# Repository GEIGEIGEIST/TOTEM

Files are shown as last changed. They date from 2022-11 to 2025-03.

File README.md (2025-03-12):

<picture align="center">
  <source media="(prefers-color-scheme: dark)" srcset="/docs/images/TOTEM_logo_dark.svg">
  <source media="(prefers-color-scheme: light)" srcset="/docs/images/TOTEM_logo_bright.svg">
  TOTEM logo
</picture>

<h1 align="center">T O T E M</h1>

TOTEM is a 38 key column-staggered choc split keyboard. It is meant to be used with a [Seeed Studio XIAO nRF52840 BLE](https://www.seeedstudio.com/Seeed-XIAO-BLE-nRF52840-p-5201.html) or [XIAO RP2040](https://www.seeedstudio.com/XIAO-RP2040-v1-0-p-5026.html).
It was created for the SEEED XIAO keyboard contest.\
[Here](https://www.hackster.io/geist/totem-a-tiny-splitkeyboard-with-splay-cb2e43) you can read about the process of making it.

***

## LAYOUT

TOTEM layout

***

## PCB

[Here](/PCB/) you can find the KiCad files and Gerbers for the TOTEM.

***

## CASE

You can use the TOTEM without a case, but [here](/case/) you can find one I made for it.

***

## BUILD GUIDE

The build guide for the TOTEM can be found [here](/docs/buildguide.md).

***

## FIRMWARE

[QMK (VIAL) precompiled](/firmware/QMK/) or [QMK (VIAL) source](/firmware/QMK/VIAL_source/) for the TOTEM (wired using the XIAO RP2040)\
[ZMK precompiled](/firmware/ZMK/) or [ZMK source (outdated)](https://github.com/GEIGEIGEIST/zmk-config-totem) for the TOTEM (wireless using the XIAO BLE)

***

## BUY

You can buy TOTEM kits and finished builds on [keeb.supply](https://keeb.supply/products/geist-totem) (based in Germany)

***

## PHOTOS

This is the TOTEM in a black resin case

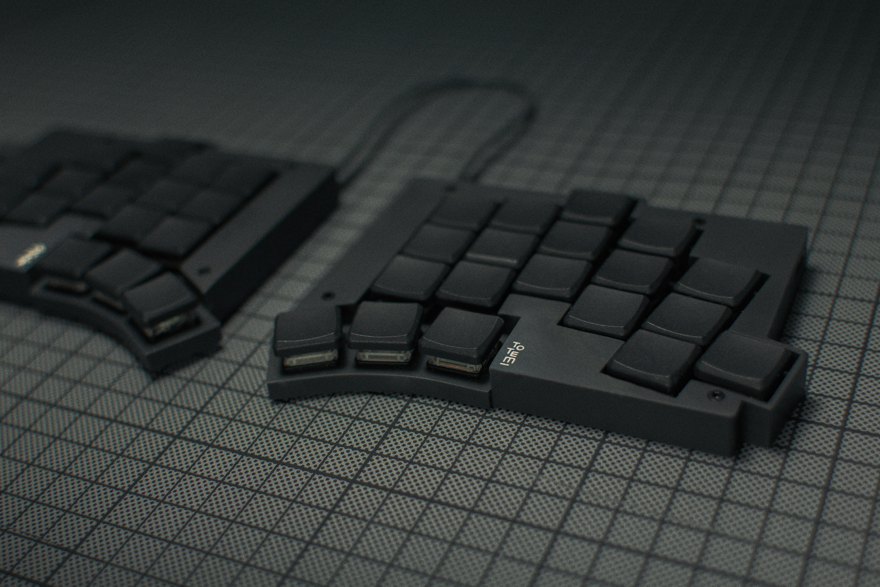
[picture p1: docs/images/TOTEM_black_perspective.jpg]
TOTEM black resin
\
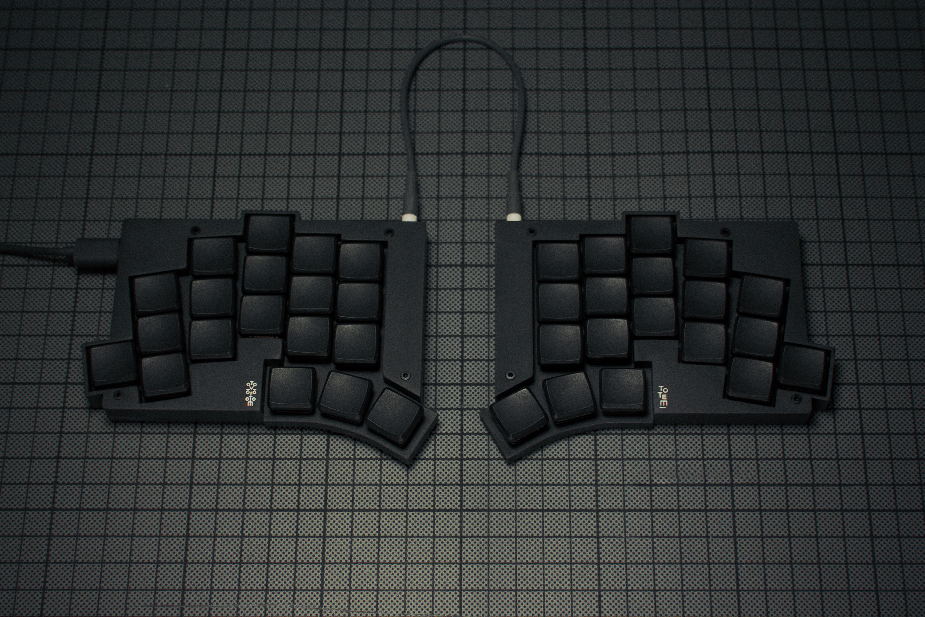
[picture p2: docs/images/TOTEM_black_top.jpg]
TOTEM black resin
\
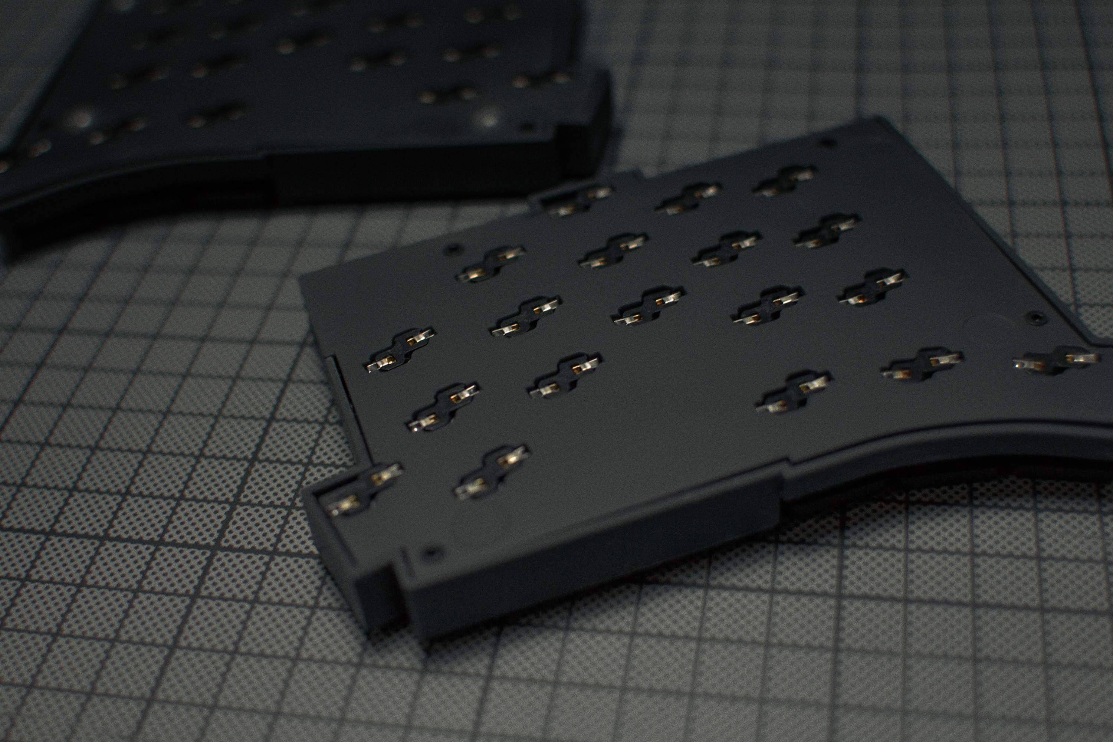
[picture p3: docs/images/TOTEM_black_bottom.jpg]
TOTEM black resin


This is the TOTEM with a black resin tenting bottom plate

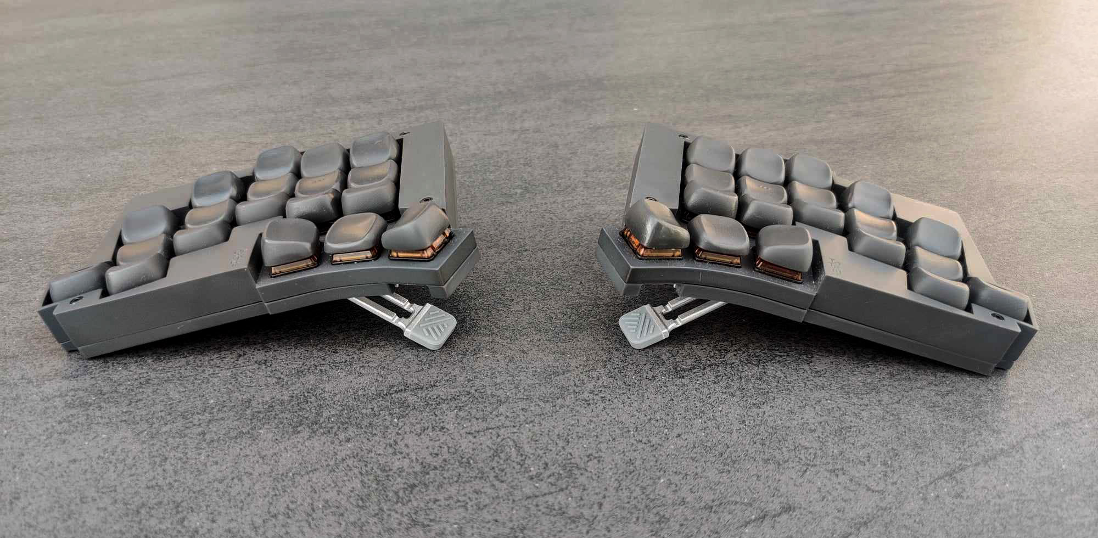
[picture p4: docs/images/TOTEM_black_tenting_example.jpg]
TOTEM black resin tenting
\
[Video by *Wolfgang's Channel* showing the tenting system in action](https://youtu.be/rvM2BthjEI4?si=mTJVdPeZstshnDyo)

***

## CREDITS

### INSPIRATION

I've added the additional pinky key to make the TOTEM compatible with the layout boards like the [Balbuzard](https://github.com/brow/balbuzard) by [Tom Brow](https://github.com/brow) and the [Osprette](https://github.com/smores56/osprette) by [Sam Mohr](https://github.com/smores56) use, where you put the keybinding of the top left and right keys on an outer pinky key.

### HELP FIXING THINGS

People who helped me create this board and fix stuff

#### PCB
- [Marco "Bob"](https://github.com/GroooveBob)

#### CASE
- [Freya](https://github.com/freya-irl)
- [Bubbleology](https://github.com/bubbleology)

#### FIRMWARE
- [Cem Aksoylar](https://github.com/caksoylar)
- [Grinnie](https://github.com/regicidalplutophage)
- [Alaa Saad Mansour](https://github.com/AlaaSaadAbdo)
- [pekudzu](https://github.com/pekudzu)

If you build a TOTEM I would be pretty happy to see some pictures. And if you want to leave me a tip you can do this [here](https://ko-fi.com/geigeigeist) (but please don't feel pressured)

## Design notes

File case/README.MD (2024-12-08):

# TOTEM CASE

Each half consists of a bottom and a top part (with an integrated switchplate) and is meant to be 3D printed in resin. 

I got good results from [JLCPCB](https://cart.jlcpcb.com/quote) (15€ + tax and shipping for a black or white version) and [PCBway](https://www.pcbway.com/rapid-prototyping/manufacture/?type=2&reffercode=TOP) (50€ + tax and shipping for a clear case).

Where possible use the STEP files, but the STL files should be fine too.

If you're sure you only will use the wired version you can also use the case without a power switch (USB) or use the case without a TRRS cutout if you plan on using the wireless version (BLE).

> **Note**
> The manufacturer will probably warn you about too thin sections, but it worked fine for me since these sections are pretty small.

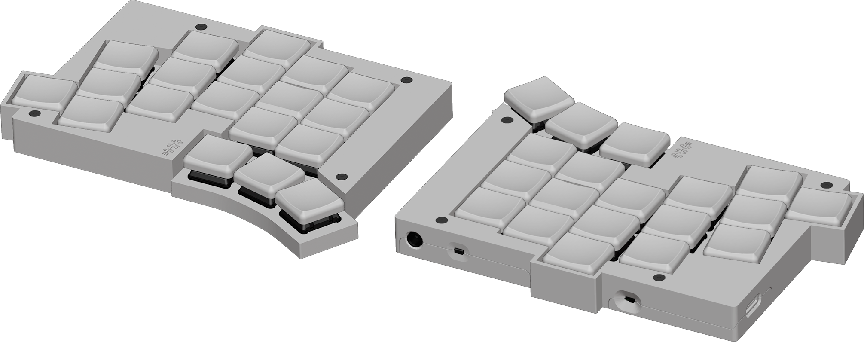
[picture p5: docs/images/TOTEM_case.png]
TOTEM case


## Tenting

Tenting is possible using the provided bottom plates found in the tenting folder. These bottom plates are compatible with their corresponding non-tenting top part. The tenting bottom plates are compatible with the same screws as the non-tenting bottom plates.

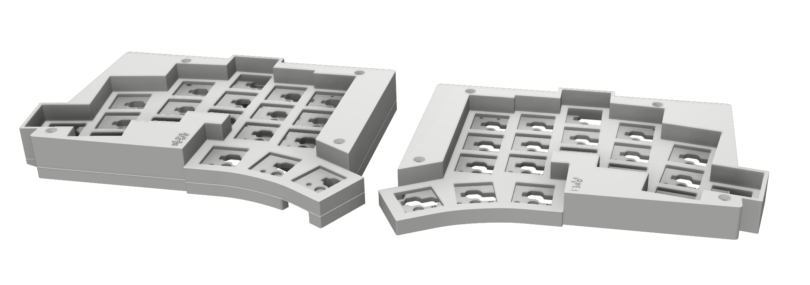
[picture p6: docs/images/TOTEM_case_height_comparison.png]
TOTEM tenting height comparison

> **Note**
>Using these tenting bottom plates (left) the keyboard height will be increased by the thickness of the tenting feet (around 4mm). Compared to the default bottom plate (right).

The tenting bottom plates are designed for [these laptop risers](https://aliexpress.com/item/1005005605228469.html).
These are attached using the provided adhesive and sit flush with the bottom of the plate.

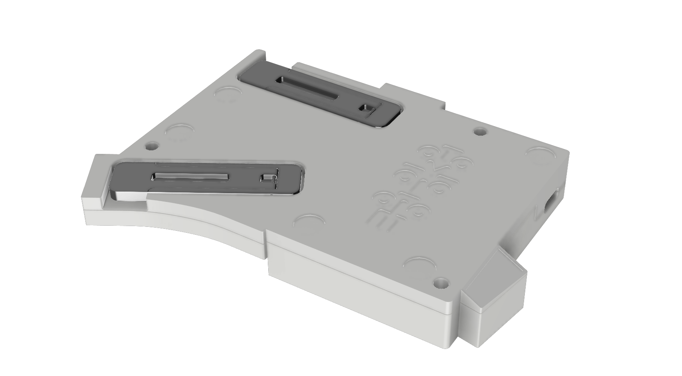
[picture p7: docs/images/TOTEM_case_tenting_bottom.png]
TOTEM tenting bottom


This system enables two tenting options: 13 and 20 degrees.
The feet allow for an even higher tenting option but this is not officially supported due to design constrains for top piece compatibility.

For optional extra grip whilst tenting there is a recess made at the pinky key designed for anti-slip adhesive pads, such as [this one](https://aliexpress.com/item/1005005377684110.html)

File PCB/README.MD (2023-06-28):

# TOTEM PCB FILES

## MANUFACTURING
If you want to get the PCB made you need to download the [ZIP](/PCB/totem_0-3/totem_0-3_gerbers.zip/) and upload it to the website of the manufacture 
I can recommend [JLCPCB](https://jlcpcb.com/), [Seeed Fusion](https://www.seeedstudio.com/fusion_pcb.html) or [PCBway](https://www.pcbway.com/).
If you want the silkscreen in yellow [AllPCB](https://www.allpcb.com/online_pcb_quote_new.html) is a pretty affordable choice.

- download [the ZIP file](/PCB/totem_0-3/totem_0-3_gerbers.zip/)
- upload the ZIP file to the website of the manufacturer.
- sometimes the Gerber preview from JLCPCB can't display the PCB, even when the files are fine. In this case use these dimensions: 258.7mm * 94.35mm
- PCB Thickness 1.6mm
- 2 layers
- PCB Qty as much as you like. One PCB is a full keyboard.
- PCB Color Black (or any other color you like)
- No impedance control
- Surface Finish HASL(with lead) if you want the easiest soldering experience or LeadFree HASL.
- Remove Order Number Yes

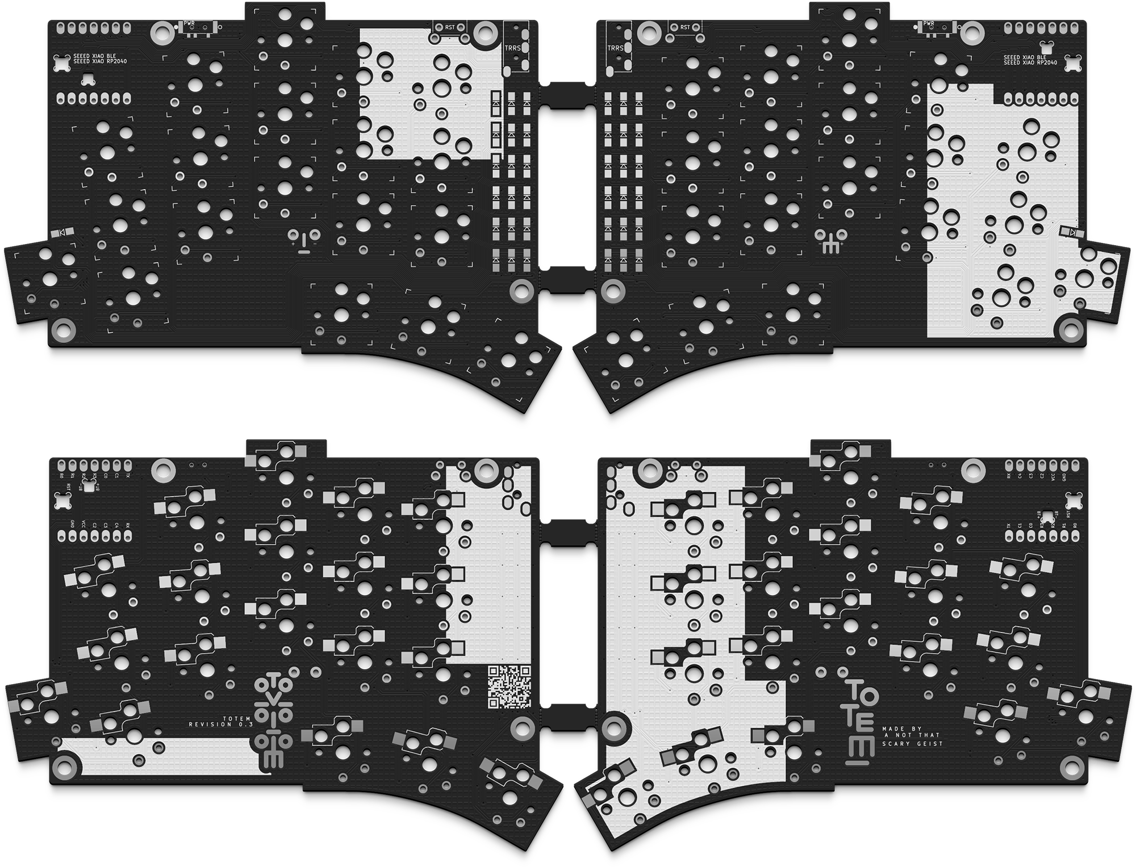
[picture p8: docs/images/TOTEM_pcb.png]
TOTEM PCB


***

## CHECK PINOUT OR TRACES

If you only want to check the traces or see what is connected to which pin you can take a look at these graphics.
You can also take a look at the [schematics](TOTEM_0-3_schematics.pdf) and the [PCB](TOTEM_0-3_PCB.pdf) as PDF.

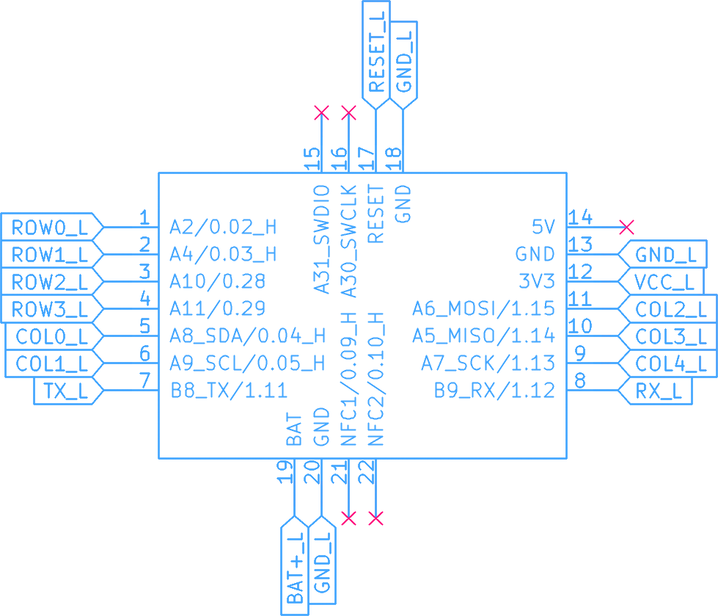
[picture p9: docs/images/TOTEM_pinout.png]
TOTEM pinout


***

TOTEM traces

***

## TAKE A DEEPER LOOK OR MODIFY 

You can download the project if you need to take a deeper look or modify something. You need the Open Source software [KiCad](https://www.kicad.org/) to open it.

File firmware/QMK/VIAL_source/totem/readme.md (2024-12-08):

```
                                                       ▀▀▀▀▀     ▀▀▀▀▀          ▀▀█▀▀
                                                       ▄▀▀▀▄  ▄  ▄▀▀▀▄  ▄  ▄▀▀▀▄  █  ▄▀▀▀▄
                                                       █   █  █  █   █  █  █   █  █  █   █
                                                        ▀▀▀   █   ▀▀▀   █   ▀▀▀   ▀   ▀▀▀
                                                              █      ▄▄▄█▄▄▄    █   █  
                                                              ▀      █  █  █     █▄█
                                                            ▀▀▀▀▀    █  █  █      ▀
                                                                     ▀  ▀  ▀
▄▄▄▄▄▄▄▄▄▄▄▄▄▄▄▄▄▄▄▄▄▄▄▄▄▄▄▄▄▄▄▄▄▄▄▄▄▄▄▄▄▄▄▄▄▄▄▄▄▄▄▄▄▄▄▄▄▄▄▄▄▄▄▄▄▄▄▄▄▄▄▄▄▄▄▄▄▄▄▄▄▄▄▄▄▄▄▄▄▄▄▄▄▄▄▄▄▄▄▄▄▄▄▄▄▄▄▄▄▄▄▄▄▄▄▄▄▄▄▄▄▄▄▄▄▄▄▄▄▄▄▄▄▄▄▄▄▄▄▄▄▄▄▄▄▄▄▄▄
       
```
# TOTEM split keyboard

TOTEM is 34 keys column-staggered split keyboard made by @geigeigeist. It uses the Seeed XIAO RP2040.

You can use this command to compile the firmware
`qmk compile -kb totem -km default`

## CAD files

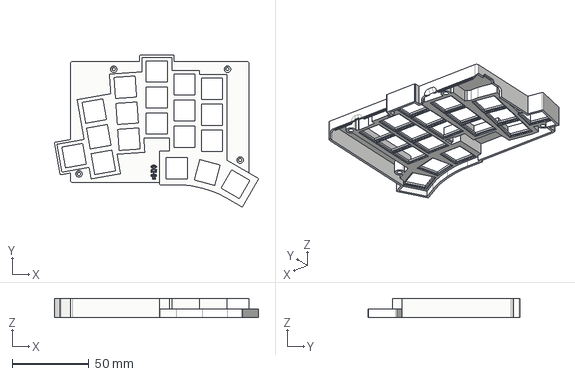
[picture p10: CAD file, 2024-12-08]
case/BLE/STEP/TOTEM_case_ble_top_L_V.08.step
133.1 x 99.0 x 12.5 mm

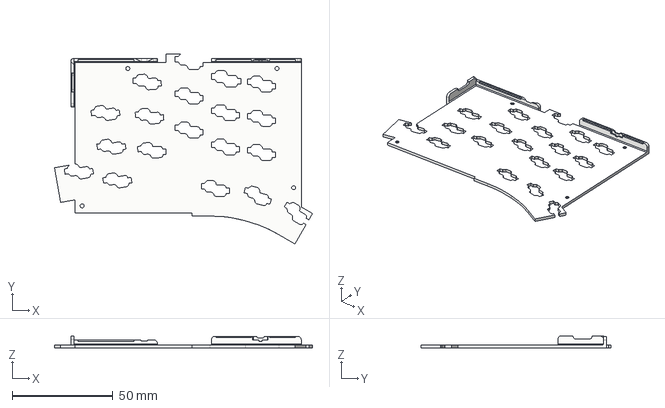
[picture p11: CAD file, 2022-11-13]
case/NoTRRS/STEP/TOTEM case_v06_noTRRS_bottomLeft.step
128.3 x 94.5 x 6.20 mm

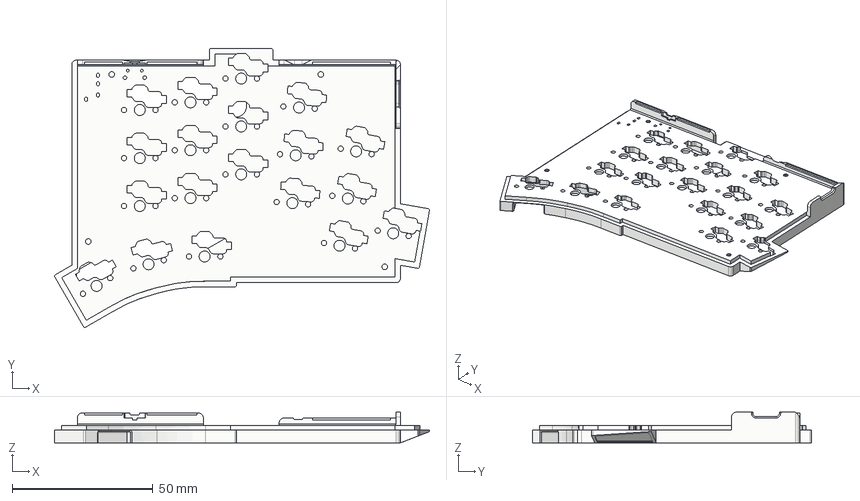
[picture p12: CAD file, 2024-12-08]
case/tenting/BLE/step/TOTEMcase_v08_6mm_BLE_Tenting_Bottom_R.step
133.1 x 99.0 x 10.9 mm

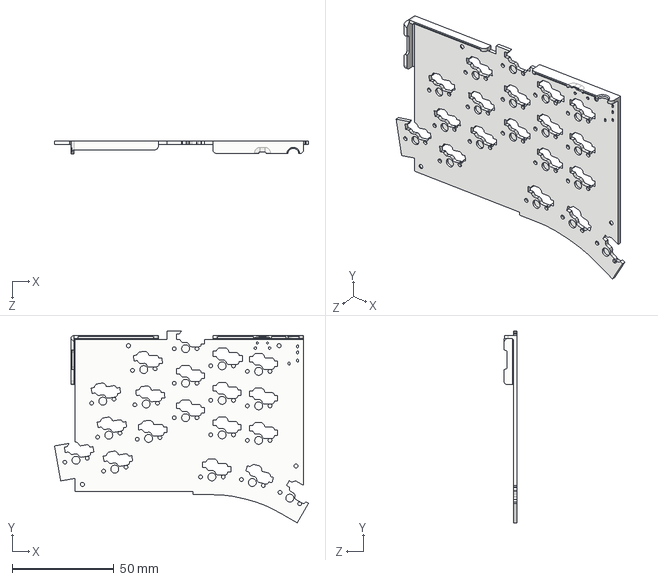
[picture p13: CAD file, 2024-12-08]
case/USB/STEP/TOTEM_case_usb_bottom_L_V.08.step
125.1 x 94.5 x 6.40 mm

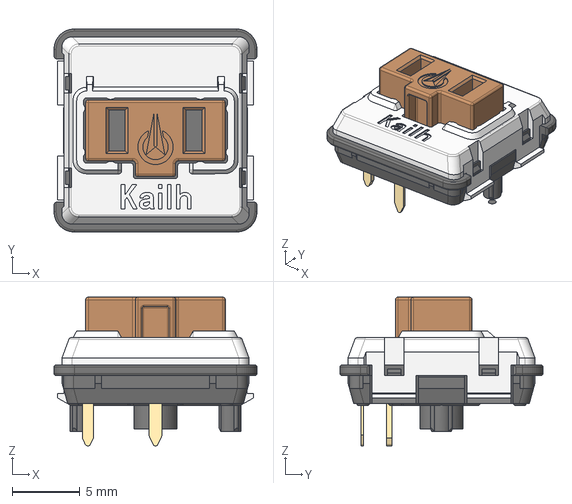
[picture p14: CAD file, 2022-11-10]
PCB/totem_0-3/TOTEM3D/Kailh_switch_PG1350_optional.step
15.0 x 15.0 x 11.0 mm

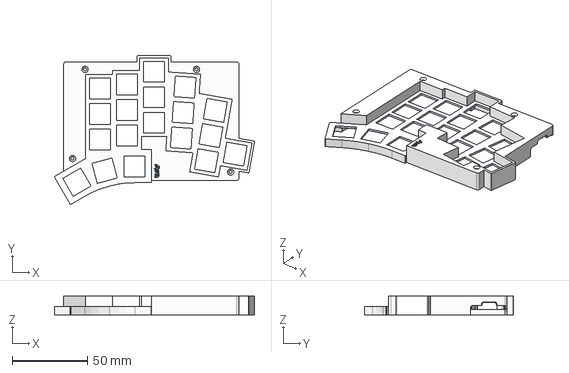
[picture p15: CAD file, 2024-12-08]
case/USB/STEP/TOTEM_case_usb_top_R_V.08.step
133.1 x 99.0 x 12.5 mm

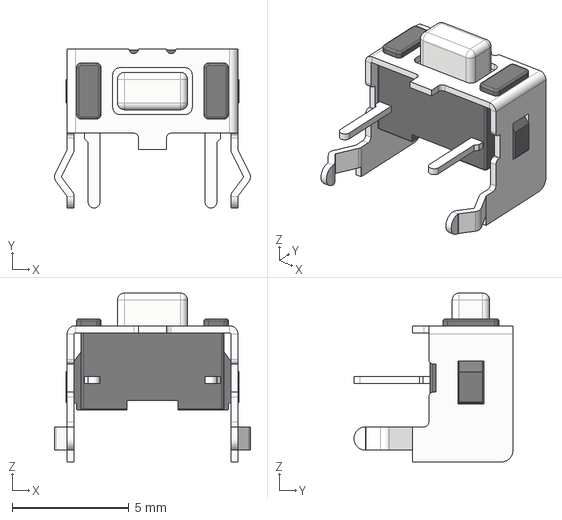
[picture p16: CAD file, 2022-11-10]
PCB/totem_0-3/TOTEM3D/SW_SKHLLC.step
8.38 x 6.80 x 7.22 mm

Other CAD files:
case/STEP/TOTEM_case_v06_Rbottom.step
case/tenting/TRX/STEP/TOTEMcase_v08_6mm_TRX_Tenting_Bottom_R.step
case/tenting/USB/STEP/TOTEMcase_v08_6mm_USB_Tenting_Bottom_L.step
case/BLE/STEP/TOTEM_case_ble_bottom_R_V.08.step
case/NoTRRS/STEP/TOTEM case_v06_noTRRS_bottomRight.step
case/STEP/TOTEM_case_v06_Lbottom.step
case/tenting/BLE/step/TOTEMcase_v08_6mm_BLE_Tenting_Bottom_L.step
case/tenting/TRX/STEP/TOTEMcase_v08_6mm_TRX_Tenting_Bottom_L.step
case/tenting/USB/STEP/TOTEMcase_v08_6mm_USB_Tenting_Bottom_R.step
case/BLE/STEP/TOTEM_case_ble_bottom_L_V.08.step
case/USB/STEP/TOTEM_case_usb_top_L_V.08.step
PCB/totem_0-3/TOTEM3D/D_SOD-123.step
PCB/totem_0-3/TOTEM3D/Kailh_socket_PG1350_optional.STEP
PCB/totem_0-3/TOTEM3D/MSK12C02.STEP
PCB/totem_0-3/TOTEM3D/PJ320A.STEP
PCB/totem_0-3/TOTEM3D/xiao-ble-tht.step
case/BLE/STEP/TOTEM_case_ble_top_R_V.08.step
case/BLE/STL/TOTEM_case_ble_bottom_L_V.08.STL
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

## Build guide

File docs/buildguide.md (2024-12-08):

# TOTEM BUILD GUIDE

## PART LIST

### REQUIRED PARTS

| Part name | Count | Remarks | 
| :---  | :---: | :--- |
| TOTEM PCB | 01 | You can find the files for it [here](/PCB/) |
| Seeed Studio XIAO| 02 | You can choose between the [nRF52840 BLE version (wireless)](https://www.seeedstudio.com/Seeed-XIAO-BLE-nRF52840-p-5201.html) or the [RP2040 version (wired)](https://www.seeedstudio.com/XIAO-RP2040-v1-0-p-5026.html) |
| Choc key switch  | 38 | Kailh Choc low profile key switches |
| diodes 1N4148W | 38 | These are surface mount diodes in SOD123 package |
| 1u Choc keycaps  | 38 | You can use the black or white keycaps from Kailh, but I recommend MBK, LDSA or CFX keycaps |
| reset button | 02 | Alps SKHLLCA010 |
| USB-C cable | 01 | For connecting the keyboard to your PC |
| power switch | 02 | MSK12C02 (only required for the Bluetooth build) |
| Lipo battery | 02 | There is space for a 15 x 22 x 7.5 mm battery (only required for the Bluetooth build) |
| TRRS jack | 02 | MJ-4PP-9 or PJ320A (only required for the wired build)|
| TRRS cable | 01 | Alternatively, you can use a TRS cable for [half-duplex](https://github.com/qmk/qmk_firmware/blob/master/docs/serial_driver.md#usart-half-duplex) (only required for the wired build)|

### OPTIONAL PARTS

| Part name | Count | Remarks | 
| :--- | :---: | :--- |
| switch socket | 38 | Switch sockets for Kailh choc switches |

### 3DP CASE PARTS

| Part name | Count | Remarks | 
| :--- | :---: | :--- |
| 3D printed case | 02 | Find the case files [here](/case) |
| 6mm M2 standoffs | 08 | 6mm round standoffs for screwing the top and bottom of the case together |
| 6mm M2 countersunk screws | 16 ||
| 8.5mm rubber feet | 8 | they can also be smaller |

### TENTING CASE PARTS
| Part name | Count | Remarks | 
| :--- | :---: | :--- |
| Additional 8.5mm rubber feet | 2 | Optional, they can also be smaller |
| Tenting feet | 4 | Example source [here](https://aliexpress.com/item/1005005605228469.html) |
| Anti-Slip adhesive sheet | 1 | Optional, example source [here](https://aliexpress.com/item/1005005377684110.html) |

## INTRODUCTION

Here is an overview of where and on which side each component needs to be soldered (click on the image to see a larger version).

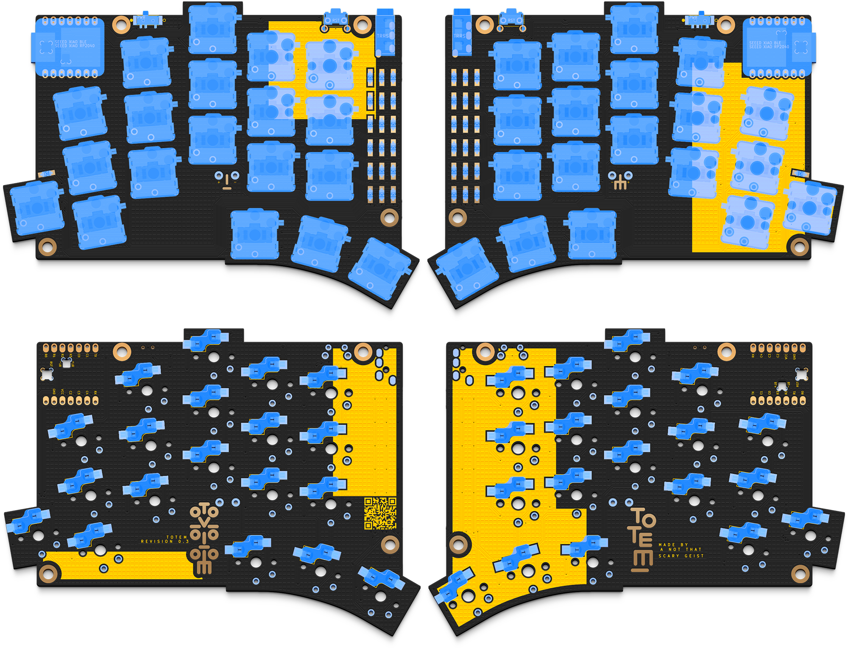
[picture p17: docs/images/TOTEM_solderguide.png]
TOTEM solder guide


***

## BREAK OFF HALVES

The PCB comes in one piece. You need to break it into two halves.

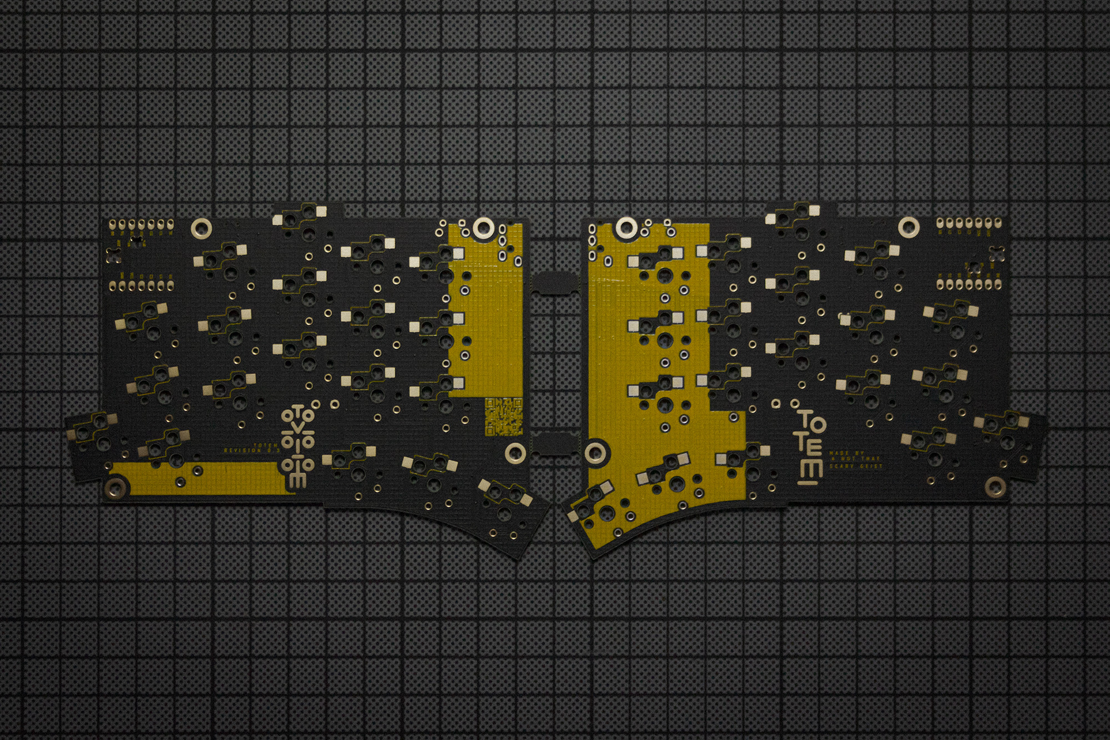
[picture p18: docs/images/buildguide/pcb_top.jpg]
TOTEM PCB


After breaking them apart, you're left with some sprue marks, which you can remove with a file if you like, but you don't need to.

> **Warning**
> You should wear a mask while doing this since the FR4 dust is considered to be toxic.

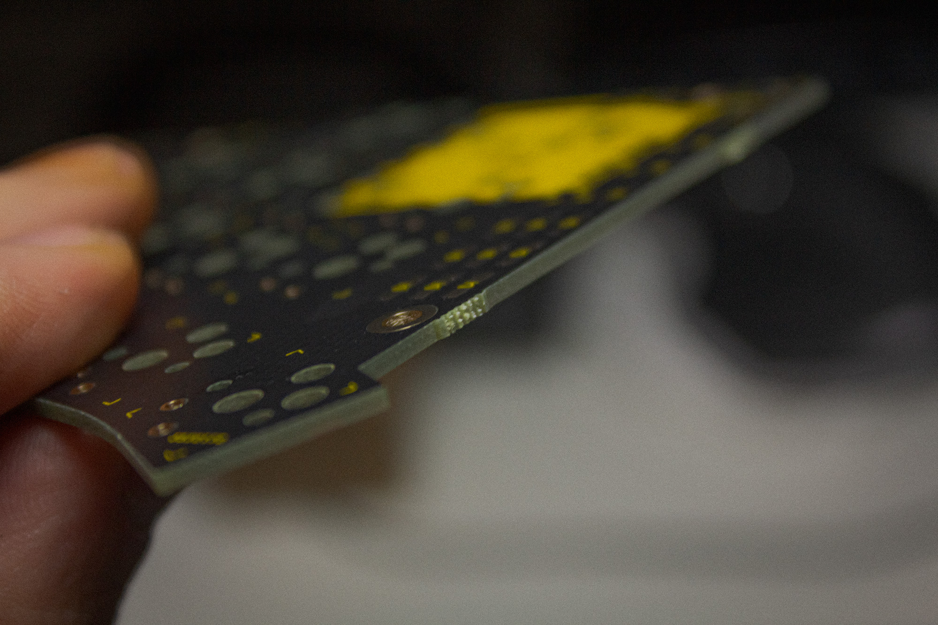
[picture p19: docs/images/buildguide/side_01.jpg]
PCB sprue marks


I paint the edges black using a sharpie, so they fit better with the top and bottom, but that's optional too.

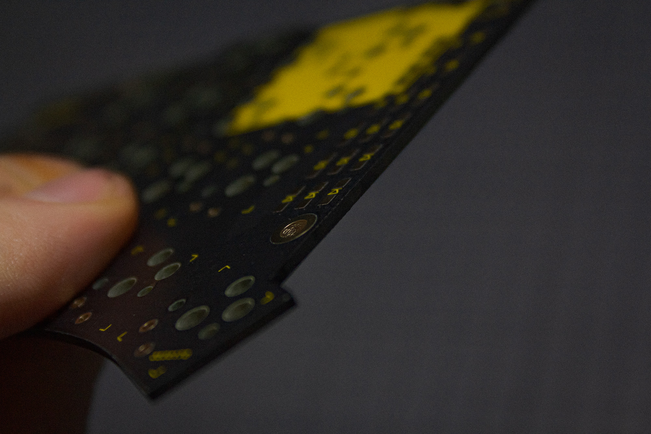
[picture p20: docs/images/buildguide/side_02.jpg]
PCB edges


***

## DIODES

The diodes need to be soldered on the top of the PCB. Pay attention to their orientation:  They have a small line on one side, which should be on the side the arrow on the PCB is facing to.

<p align="center">
<picture>
  <source media="(prefers-color-scheme: dark)" srcset="/docs/images/buildguide/diodes_dark.svg">
  <source media="(prefers-color-scheme: light)" srcset="/docs/images/buildguide/diodes_bright.svg">
  diode orientation
</picture>
</p>

Apply a small amount of solder on one pad.

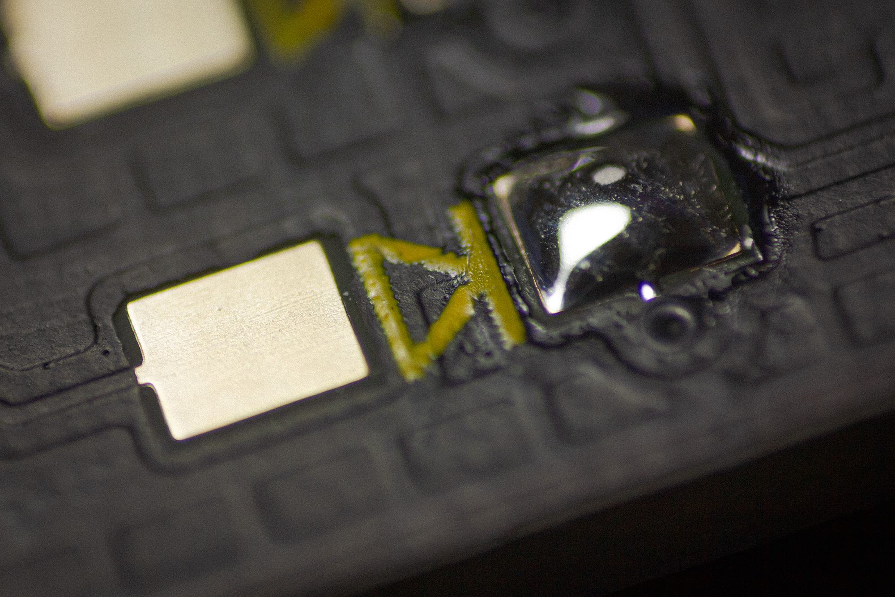
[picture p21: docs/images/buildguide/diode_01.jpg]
Solder on one pad


Then use tweezers to place the diode on the pads and reheat the solder to secure the diode.

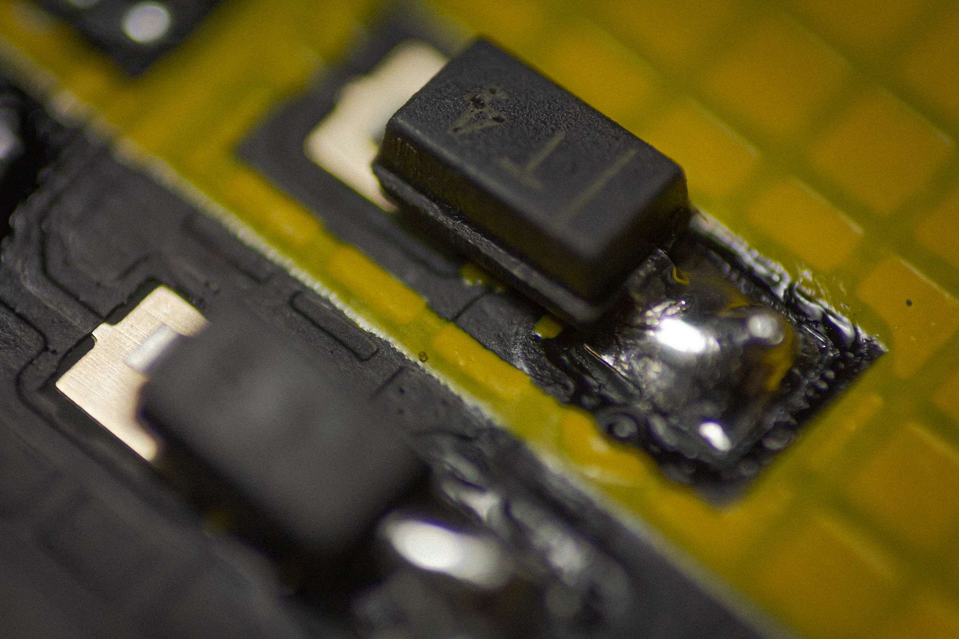
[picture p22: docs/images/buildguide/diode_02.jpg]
Solder diode


Now you can solder the second pad.

***
 
## SWITCH SOCKETS (optional)

Here you can apply the same technique as used for the diodes: Apply some solder on one of the pads first.

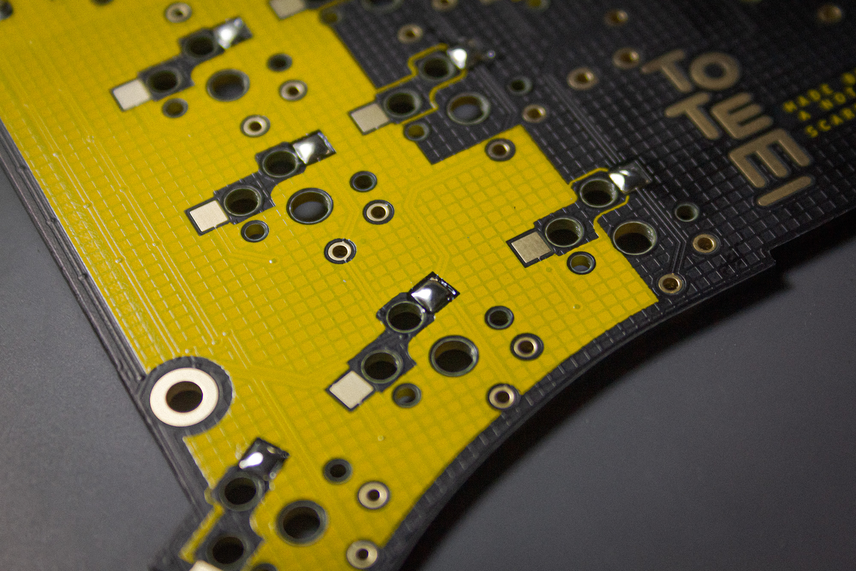
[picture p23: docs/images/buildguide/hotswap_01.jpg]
switch sockets pad


Then place the switch socket in the silk screen markings. The orientation matters here too. Especially if you plan on using the case.

<p align="center">
<picture>
  <source media="(prefers-color-scheme: dark)" srcset="/docs/images/buildguide/socket_dark.svg">
  <source media="(prefers-color-scheme: light)" srcset="/docs/images/buildguide/socket_bright.svg">
  hotswap socket orientation
</picture>
</p>

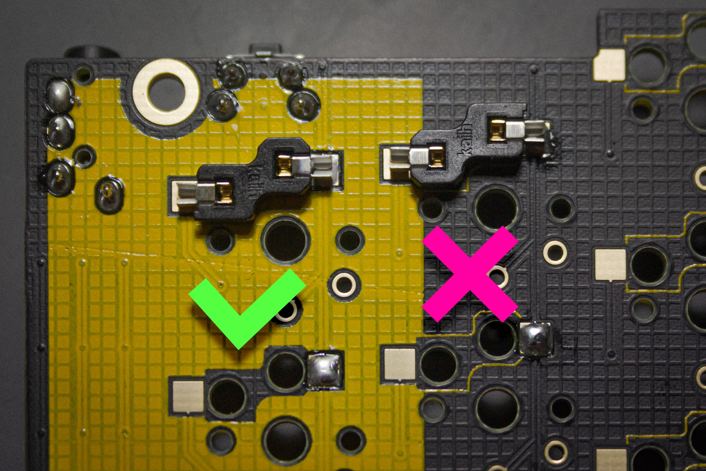
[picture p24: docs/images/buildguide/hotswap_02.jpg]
hotswap socket right and wrong orientation


Then reheat the solder. 
Apply some pressure with a pair of tweezers to make sure the socket is fully seated.\
Now solder the second pad.

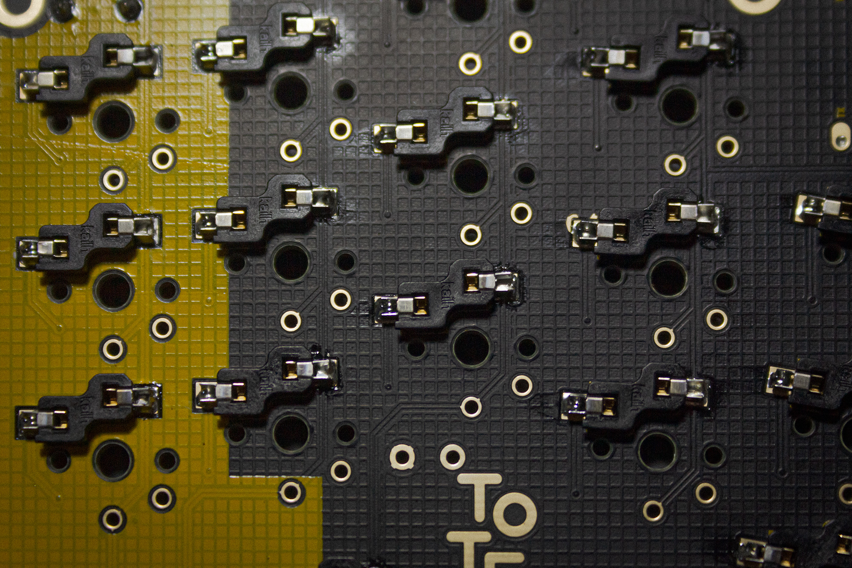
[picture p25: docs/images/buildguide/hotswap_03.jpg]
switch socket soldered


***

## POWER SWITCHES (only required for Bluetooth build)

Apply a tiny bit of solder on the bigger, outer pads on top of the PCB. 

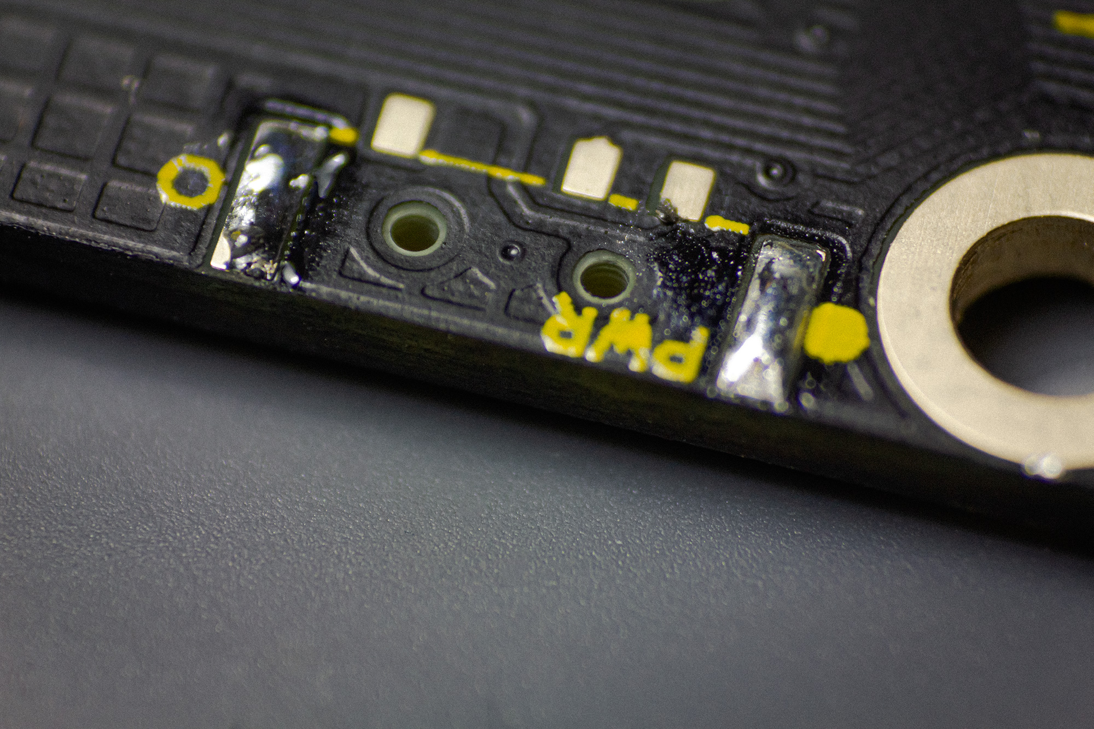
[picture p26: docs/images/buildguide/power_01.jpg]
power switch pads


The power switch has some tiny knobs on its bottom, which fit into the PCB holes. Hold it in place with tweezers and then reheat the solder on the pad. After this, you can solder the other pad and the three pins.

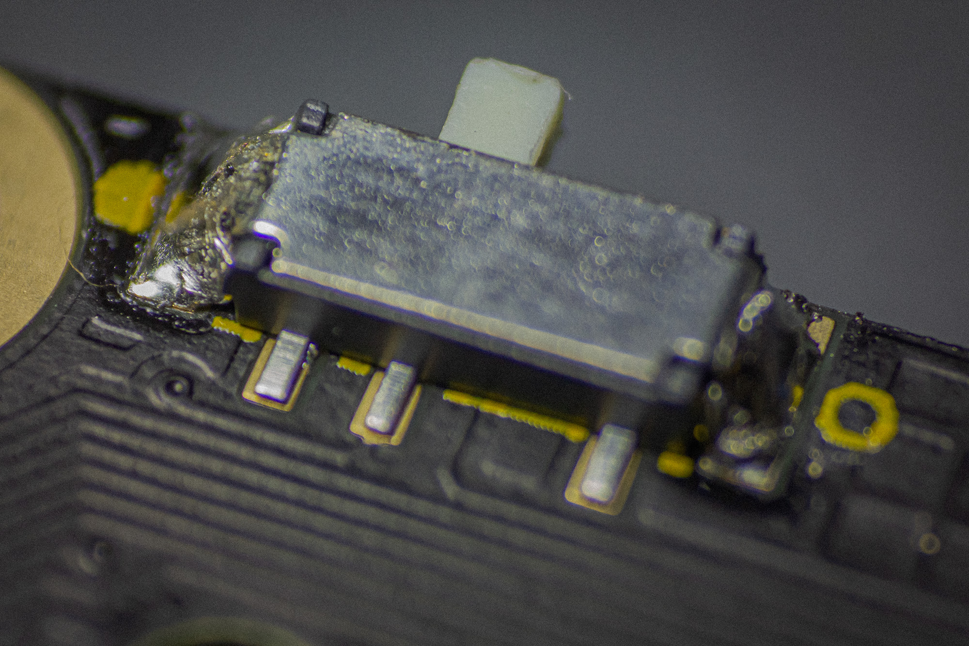
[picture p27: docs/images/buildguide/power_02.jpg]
power switch


***

## RESET SWITCHES

Insert the switch into the top of the PCB. 

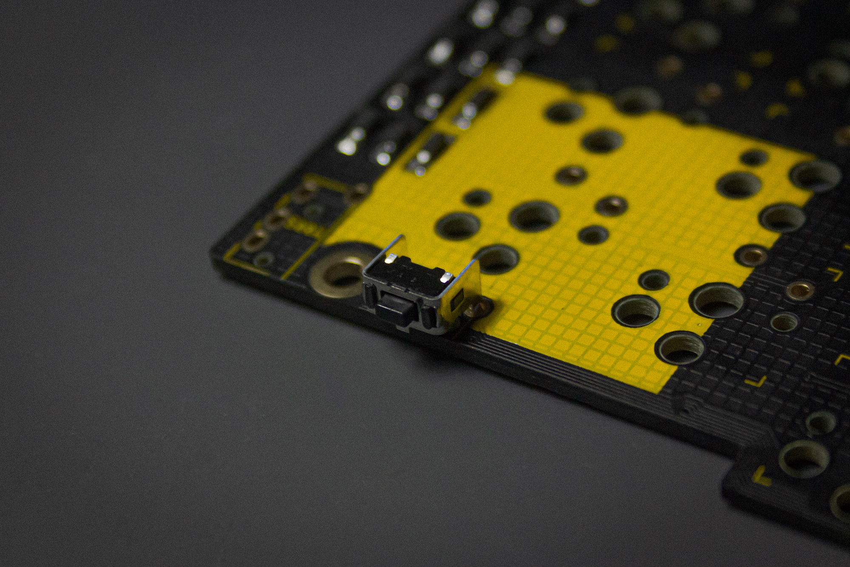
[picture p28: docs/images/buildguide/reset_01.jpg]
reset switch


I placed the footprint a bit more towards the edge, than it's meant to be, to integrate it better into the case. Therefore the tiny stabilizer on the bottom of the switch doesn't touch the PCB anymore. Make sure it is aligned with the PCB vertically, so it's oriented correctly.

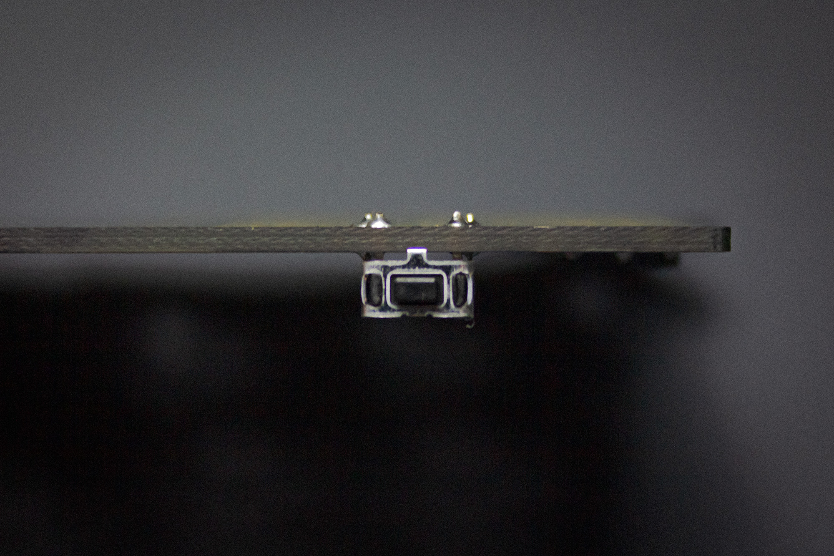
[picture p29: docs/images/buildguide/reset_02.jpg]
reset switch orientation


Then solder the four pins on the bottom to the PCB

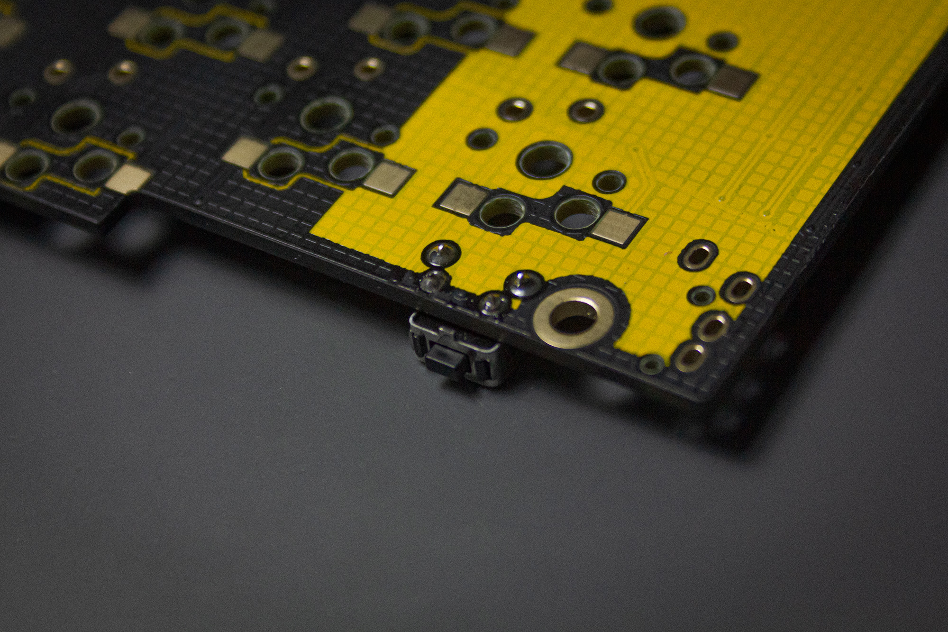
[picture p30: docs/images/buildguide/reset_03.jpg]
reset switch solder


***

## TRRS JACKS (optional)

> **Warning**
> You don't need the TRRS jacks for running the TOTEM with ZMK. Actually, you can damage your board when connecting it through TRRS, while also connected to a battery.

Install the TRRS jack on the bottom side of the PCB. The place where you should insert it is marked with a white line.

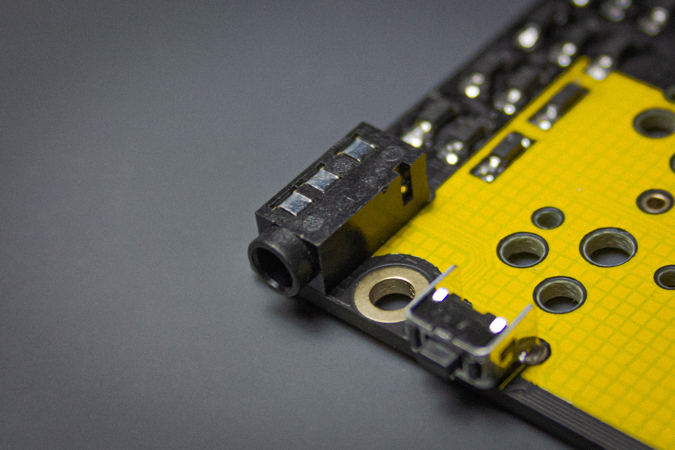
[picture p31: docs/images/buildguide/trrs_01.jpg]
TRRS jack


You may want to use some masking tape to hold it in place since you need to solder it on the bottom.

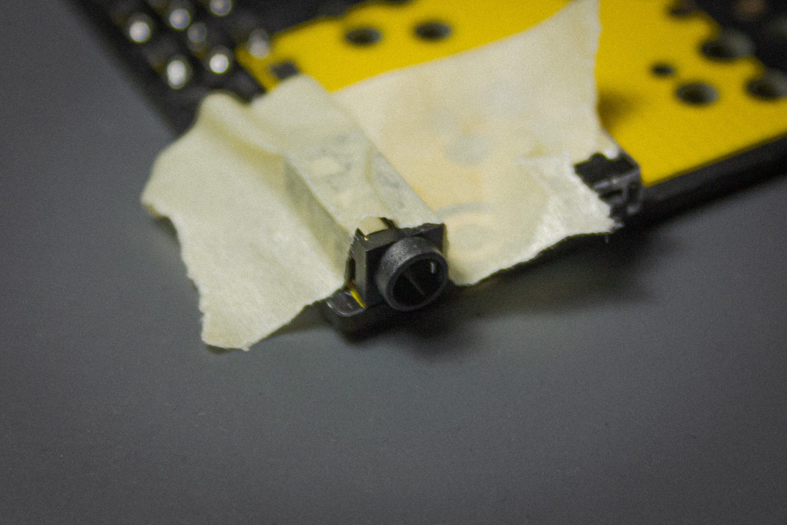
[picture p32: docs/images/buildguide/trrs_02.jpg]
TRRS jack taped


Then solder the pins on the bottom to the PCB.

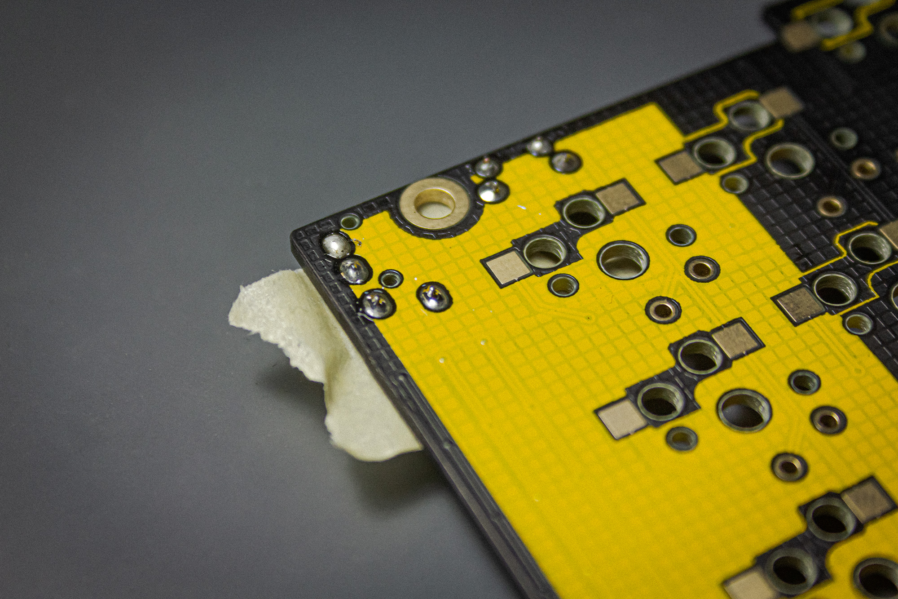
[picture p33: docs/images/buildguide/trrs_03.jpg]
TRRS jack soldered


***

## MICROCONTROLLER

> **Warning**
> First flash the microcontroller to make sure it works, before soldering it in. Especially since you can't use sockets.

Place the microcontroller in its place. 

> **Note**
> If you're struggling with keeping it in place you can use the headers, which came with it, and some double-sided tape. But make sure it sits flat on the PCB. Otherwise, the case won't fit.

Apply some flux and try to hold the iron at an angle where you touch the pads of the microcontroller and the PCB while adding solder.

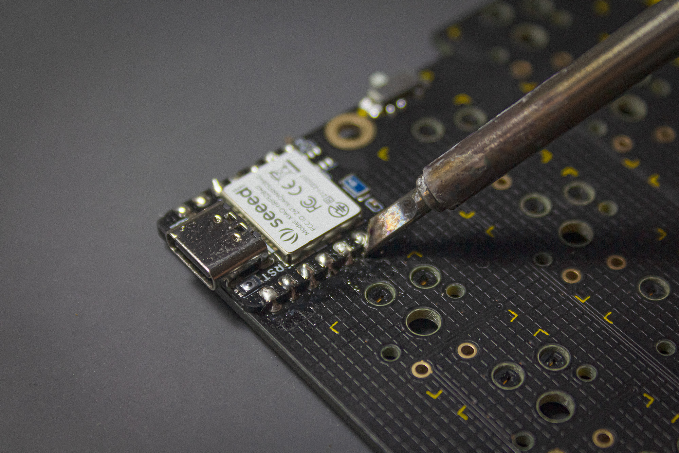
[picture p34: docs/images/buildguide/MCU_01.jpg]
soldering MCU


The pads on the back are a bit fiddly to solder, so you should add a lot of flux to the pads on the microcontroller first. Then apply the same technique as on the front: Try to touch the pads on the microcontroller and the PCB before adding solder. 

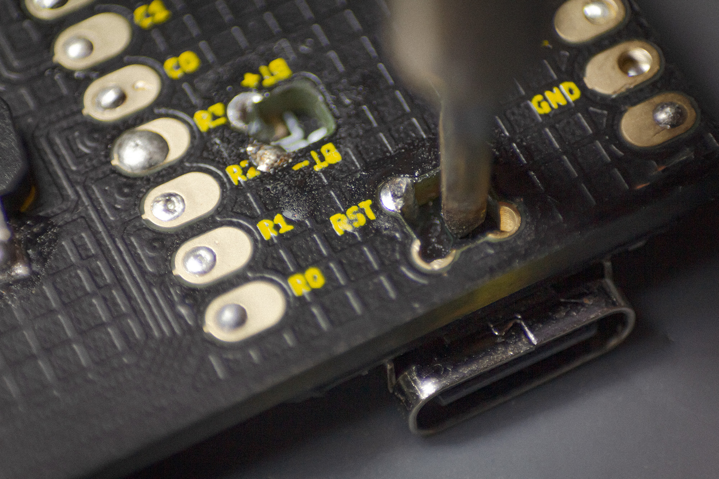
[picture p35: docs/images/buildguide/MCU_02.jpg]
soldering MCU back


***

## BATTERY (optional)

> **Warning**
> You don't need the battery for running the TOTEM with QMK. Actually, you can damage your board when connecting it through TRRS, while also connected to a battery.

You probably need to shorten the cables and tin them, since the length needs to be pretty short, to fit. I've also plasti dipped mine.

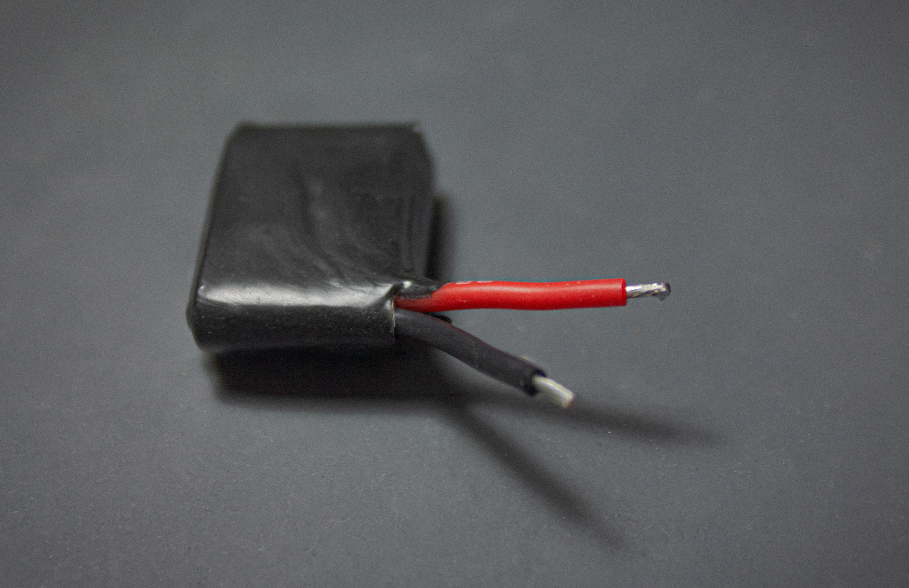
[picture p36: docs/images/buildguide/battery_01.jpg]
shorten battery cables


> **Warning**
> Before attaching the battery in any way to the PCB set the power switch to off (right on both sides).

You can see which cable needs to go in which eye by the silkscreen below the eyes. Red is + / Black is -.

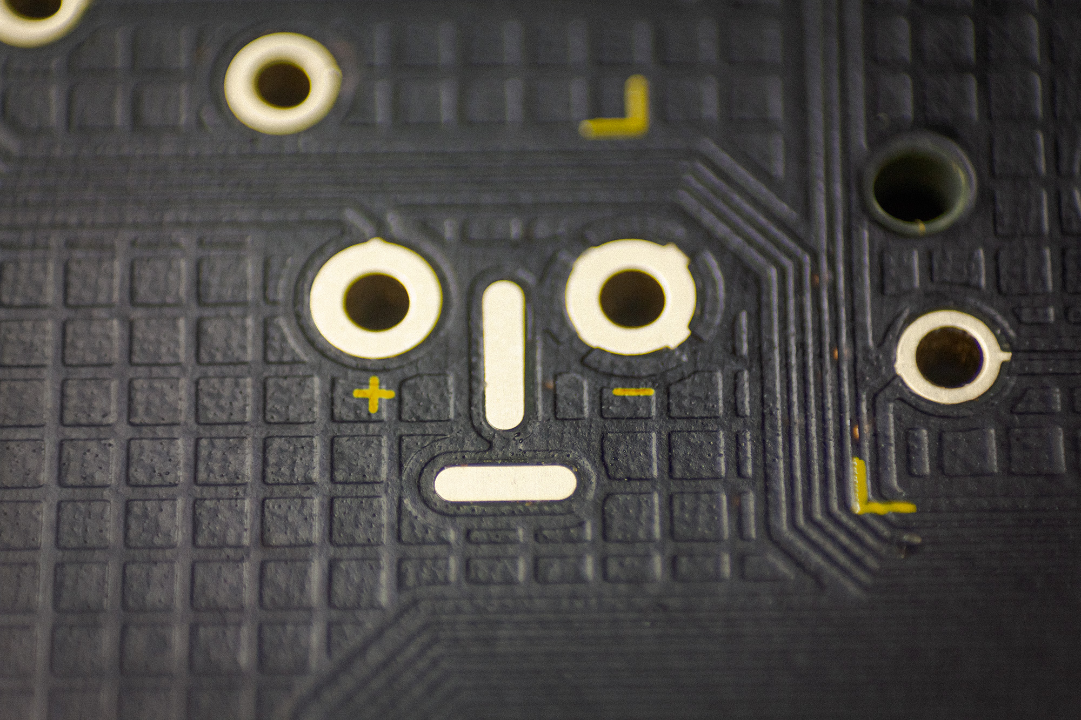
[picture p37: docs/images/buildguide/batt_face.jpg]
battery face


Attach the wires of the battery to the pads and solder them in.

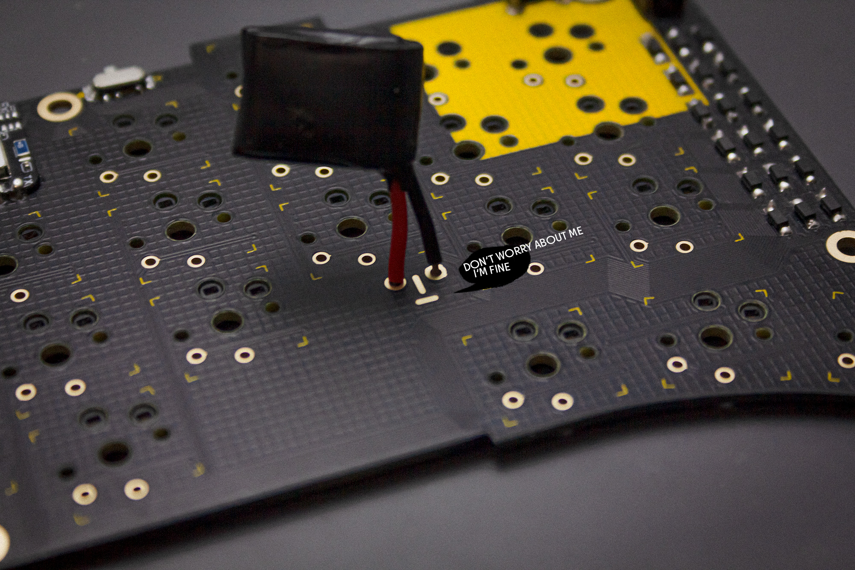
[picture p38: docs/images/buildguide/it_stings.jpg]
Ouch


***

## CLEANING

You can use an old toothbrush and some isopropanol to clean it from residues. 

***

## FIRMWARE

If you have not already flashed the firmware to the microcontroller you should do it now.\
[Here](https://github.com/GEIGEIGEIST/zmk-config-totem) you can find the ZMK firmware for the TOTEM.\
[Here](https://github.com/GEIGEIGEIST/qmk-config-totem) you can find the QMK firmware for the TOTEM.\

Probably a good idea to also install switches to make sure all of them work, before inserting the board into the case.

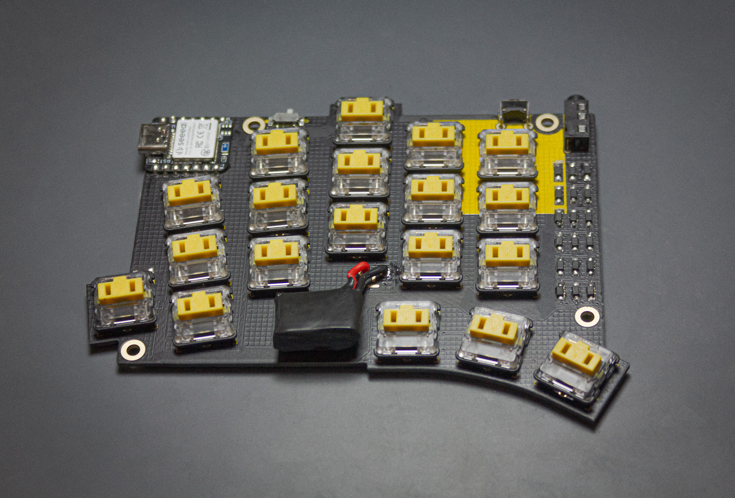
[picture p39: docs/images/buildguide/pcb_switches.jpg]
PCB with switches


***

## CASE

> **Note**
> I'm using the transparent version of the case, so it's easier to see where everything goes, but it's identical to the black/white case.

First, install the standoffs from below into the top of the case.

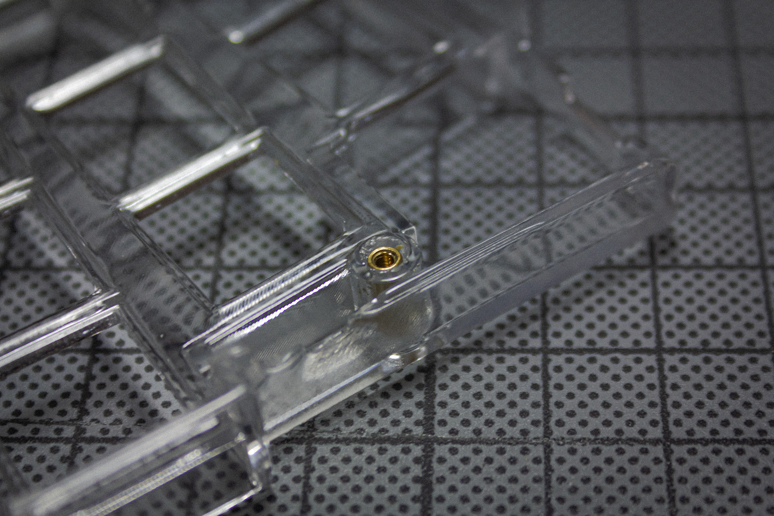
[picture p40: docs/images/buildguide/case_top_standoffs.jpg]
Top case with standoffs


Next screw them in from above.

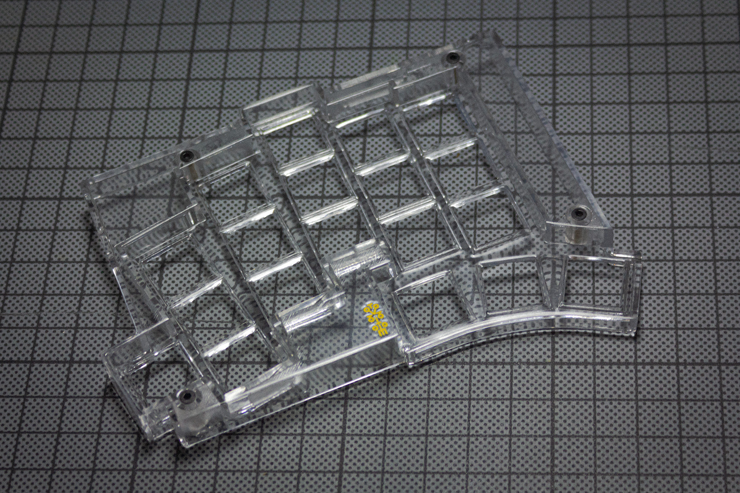
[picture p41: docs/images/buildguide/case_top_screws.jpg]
Top case with screws


Now insert the board into the top and connect them using the switches.

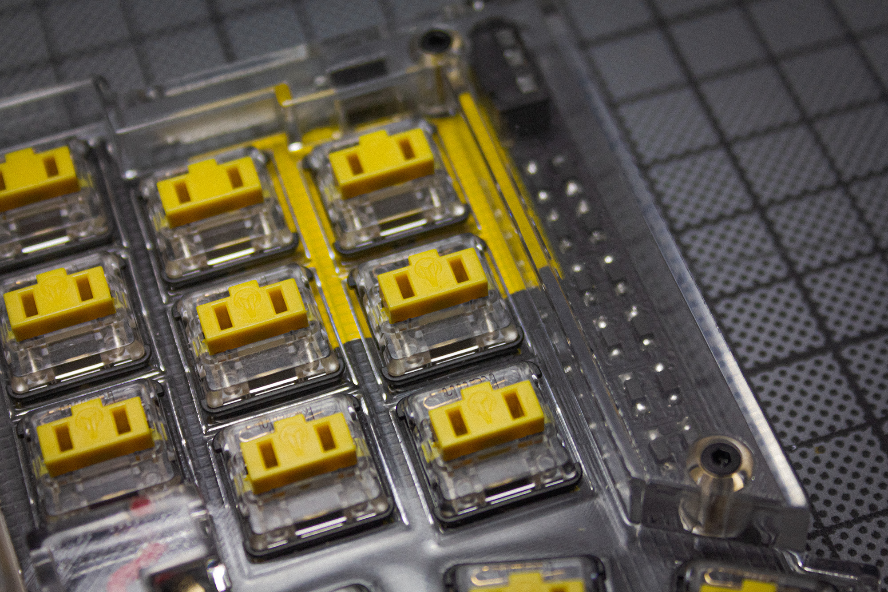
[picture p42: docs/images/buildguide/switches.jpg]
Top case with switches


The bottom has some insets for using rubber feet. 

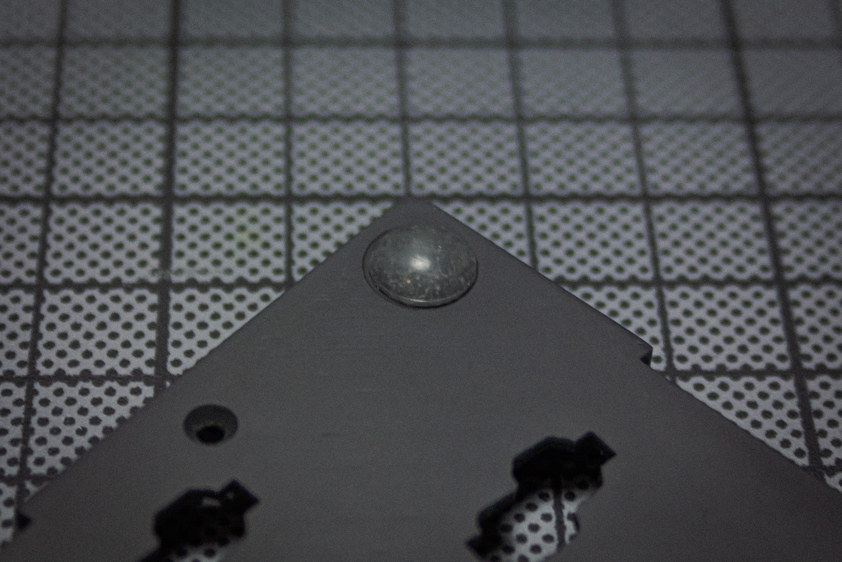
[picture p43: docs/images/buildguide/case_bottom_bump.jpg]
bottom case insets


You can then attach the bottom to the case and screw it in. 

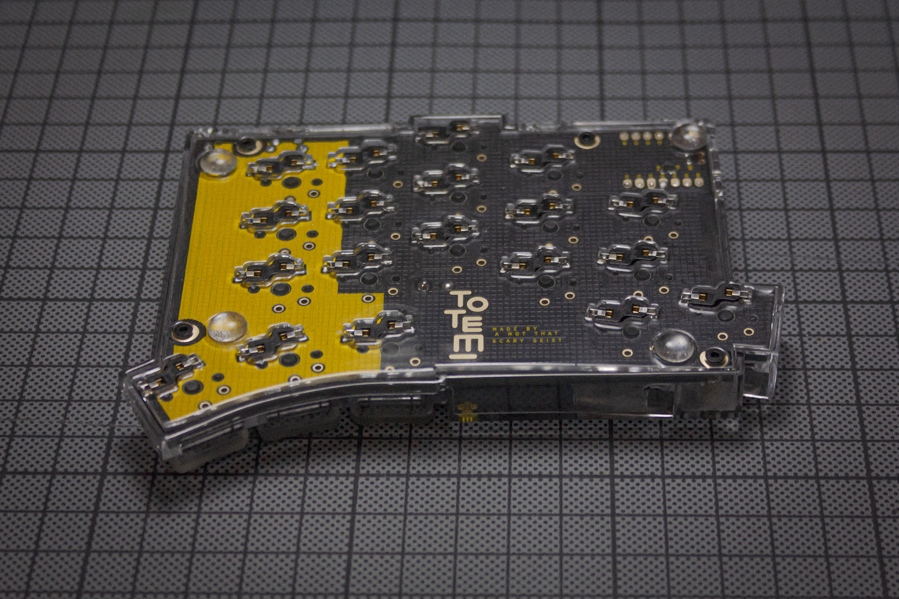
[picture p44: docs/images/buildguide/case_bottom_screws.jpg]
bottom case screws


***

## FINAL BUILD

This is what the final keyboard will probably look like. 

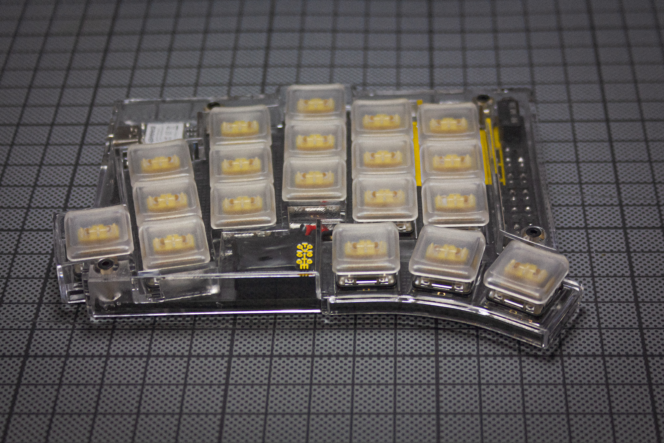
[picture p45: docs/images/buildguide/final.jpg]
final build


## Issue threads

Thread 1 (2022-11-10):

36 keys version

toniz4, 2022-11-10:
Hello! This is a awesome design, the only problem for me is the outer pinkie key.

It would be easy for me to modify the pcb file to remove that key, the problem is in the case files. I can only barely use freecad, and by what I saw, there is only the stl and step files avaliable.

So, it's possible to release a 36 key version of the TOTEM in the future?

Thanks!

GEIGEIGEIST, 2022-11-10:
Hi Toniz4,
Unfortunately I don't plan to do different layouts with this board. I'll upload the PCB files today. And I can upload the Fusion360 files too, so people can modify it themself.

toniz4, 2022-11-10:
That's fine, Either way I'm building one for myself, that's a really nice design and it's nice to try other layouts. Just out of curiosity, in your personal layout, what key do you bind that outer pinky key?

Another unrelated question, what is the model number of the battery that you used? The biggest battery that i found is a 601417 with 150mah (https://a.aliexpress.com/_mqxZTWy). Maybe you managed to find a better one.

GEIGEIGEIST, 2022-11-10:
Thank you. I've added the pinky key to also support layouts where you use the pinky key for the letter usually on the top left and top right like the [Balbuzzard](https://github.com/brow/balbuzard).

I use a 751517 from Walkera (100mah) after never receiving [this one](https://aliexpress.com/item/1005001812754397.html) I ordered at AliExpress (the problem was the logistics company)
Unfortunately I can't take a look at the one you've linked, cause they probably doesn't ship to Germany.

toniz4, 2022-11-10:
Thanks for the info!

Closed 2022-11-10.

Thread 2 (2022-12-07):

JLCPCB won't render a preview image or detect the PCB lengths

marcleonschulz, 2022-12-07:
I don't if it is “normal” that JLCPCB don't give any preview image or other information from the grabber files.

GEIGEIGEIST, 2022-12-07:
Yea unfortunately this is normal (at least with most boards I've done so far). I don't know why this happens, but it views fine on other sites like OshPark, Seeed or PCBway

Closed 2022-12-08.

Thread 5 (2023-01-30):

"Bottom Right" STL file is missing

dlehman, 2023-01-30:
The bottom right STL file (TOTEM_case_v07_bottom_right.stl) in the "/case/STL/" folder appears to be missing.

Closed 2023-05-17.

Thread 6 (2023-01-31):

Tenting support

ar-qun, 2023-01-31:
Hello GEIGEIGEIST,

I really liked you keyboard and was wondering if tenting is possible with this keyboard?

Would be interesting to use it with Manfrotto tripods.

Also would it be possible to buy a pre-build version?

GEIGEIGEIST, 2023-01-31:
Hi ar-qun,
Unfortunately tenting isn't possible, since I couldn't fit the footprint for the SplitKB puck in my PCB, without making to many compromises.
A pre built version isn't planed, but at least a kit will be available soon.

dlehman, 2023-01-31:
@GEIGEIGEIST Any idea what timeframe for kit will be? Considering ordering my own parts, but would be willing to wait a bit for a kit.

Wanderwichtl, 2023-02-06:
@GEIGEIGEIST I am currently thinking about building a copy of your awesome Totem. Is it worth it to wait for the kit, and what will it include?
Would it be possible to make it to a wireless version on my own?
Will it include a (transparent) case?
Will it be a standard PBC?

Closed 2023-02-03.

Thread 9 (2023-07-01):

[Question] Use both wireless mode and wired mode

gangjun06, 2023-07-01:
According to the document, I can't connect two boards with TRRS cable while connected to the battery.
But I want to use both wired mode and wireless mode. Is it possible?
Should I re upload firmware (ex: QMK to ZMP) each time I change mode?
Sorry If it's dumb question

Also, I want to know the battery duration of the keyboard.

gangjun06, 2023-08-11:
I think it is not a proper question for this keyboard repository.
It is question about ZMK.

Anyway, I created and it works perfectly for me.

Closed 2023-08-11.

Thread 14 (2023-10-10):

Recommendations on 3D Case and Information on Material Safety and Surface Finish

sedghi, 2023-10-10:
Thank you for sharing this excellent build. I have made the decision to proceed with building one myself. Your recommendations regarding the PCB options, such as the number of layers and thickness, were truly helpful.

I would greatly appreciate it if you could provide some recommendations for the 3D case as well. There seems to be an overwhelming number of options available, and I am unsure about which one to choose. I have come across information suggesting that resin can be toxic. Is this true for all materials used in the case, or are there some alternatives that are safer? Additionally, I would like to know more about the surface finish.

By the way, I really like the case design that you featured in the image. Could you please share the options that were used to generate it in JLCPCB?

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

spamwax, 2023-10-12:
I used pcbway.com and selected "Resin Standard white material (UTR 8360)", and it looks and feels great. I am not sure about toxicity of it!

spamwax, 2023-10-13:
No, I used pcbway because the other one didn't accept the file I was uploading

ivandaho, 2024-09-01:
Leaving this here in case someone else finds it useful - I also had difficulty deciding the options for the case.

These settings worked for me for printing the case via JLCPCB, with the exception of a small chip on the left half, near the thumb cluster breaking off. It's not critical and i was contacted by them about it.

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

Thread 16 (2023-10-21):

Question about case compatibility?

jittapont, 2023-10-21:
I want to ask about the case compatibility between the USB version and BLE version. Can I use the USB version (https://github.com/GEIGEIGEIST/TOTEM/tree/main/case/USB) first and change to wireless option with the same case?
Thanks a lot

spamwax, 2023-10-22:
I believe it is compatible. Just make sure you disconnect the TRS cable between the two halves when you install the battery.

isopix, 2023-10-30:
What happens if we forgot to disconnect it? Can some components be damaged?

spamwax, 2023-10-30:
> What happens if we forgot to disconnect it? Can some components be damaged?

Yes, according to the build [guide](https://github.com/GEIGEIGEIST/TOTEM/blob/main/docs/buildguide.md#trrs-jacks-optional), it can damage it.

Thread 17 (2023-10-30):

https://keeb.supply/products/geist-totem doesn't work - We couldn't find any product at that address!

isopix, 2023-10-30:
https://keeb.supply/products/geist-totem doesn't work - We couldn't find any product at that address!

And I live in EU(Poland)

lemcz, 2023-11-06:
@isopix I also live in Poland, HMU if you're interested in buying a PCB (I can assemble it for you). I also ordered 3d printed case from jlcpcb, so I can help out with that process.

Other than that - this is not an issue for the author of the keyboard, but store's and AFAIK (I've asked on their discord), they are not going to re-stock on TOTEM any time soon.

isopix, 2023-11-06:
> @isopix I also live in Poland, HMU if you're interested in buying a PCB (I can assemble it for you). I also ordered 3d printed case from jlcpcb, so I can help out with that process.
>
> Other than that - this is not an issue for the author of the keyboard, but store's and AFAIK (I've asked on their discord), they are not going to re-stock on TOTEM any time soon.

It's awesome looking and most compact keyboard. If some trackpad/trackpoint (or other pointing device) would be added, then it would be perfect travel keyboard (there are already keyboard with slim choc switches and custom trackpoint assemblies)

Currently I have very limited budget, and now I'm much more interested in wireless Charybdis:
https://bastardkb.com/product/charybdis-nano-premium-diy-kit/
https://github.com/Bastardkb/Charybdis

I haven't found anyone in EU(except official shop, where this premium set costs 800eur, but it's not even wireless [so it needs different controller, trackball optical sensor and PCBs]) that would sell me PCBs (especially wireless version)
There are also other mods, including 2nd trackball, encoders, etc.
It's like nylon prints costs 100eur for pair, the same for four metal plates (in Netherland, can only hope in Poland it's cheaper).
This are prices from jlcpcb, that makes PCBs and nylon prints (that are sanded too. BastardKB also orders from them, so it would look identical)

I never ordered anything 3d printed or jlcpcb and don't know metal laser-cutting prices in PL. I've simply contacted all the people that were hanging in discord server, that made wireless version, and everyone  replied that he sold his spare boards already(I've heard it's way cheaper to order multiple PCBs at once and that one set is not viable).

I didn't had enough pressure to start ordering it by myself, because there are improvements going all the time(especially as mods/forks).

Anyway feel free to contact me at krzysztof dot krakowiak at some popular 'G' provider, because Github doesn't allow direct messaging ;-)

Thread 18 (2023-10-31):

Issue with Totem Keyboard: Few Keys Not Working After a Few Days

marczen, 2023-10-31:
## Description:
Hello,

I'm a beginner in keyboard building and recently assembled my Totem keyboard. I've been enjoying it, but I encountered an issue where certain keys stopped working after a few days of use. I've attached an image to illustrate the problem.

## Problem Details:
The issue has persisted despite my attempts to troubleshoot, which included checking switches and hotswap sockets.
I'm not sure if the problem might be related to diodes, or why specifically these three keys are affected.
I would greatly appreciate any guidance or ideas on what might be causing this issue and how to resolve it.

Thank you for your assistance!

*(image of keys that don't work)*
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

dedebenui, 2023-11-16:
Hi! I'm also a beginner. I built the wireless Totem a 2 weeks ago and the left half (just like you!) had a few keys not working. I measured a bunch of paths with my multimeter in diode mode and noticed that I had some voltage drop across a diode even in reverse. I desoldered every diode and socket on the left board and could still measure a voltage drop across the pads of the faulty diode even though nothing was connected there, so it wasn't the diode's fault. Since I had spare boards because of the minimum order quantity, I soldered everything again on a new one and it still doesn't work: some keys don't work at all and some keys, like my `t` key sometimes randomly outputs a few adjacent letters in one press.

I had no issue with the right half.

I suspect that I make a mistake when I solder the controller and, because it's a difficult part to solder, I leave my iron too long on the contact point or press too hard, or something else. The result is a damaged trace on the board that sort of shorts 2 traces together. If I measure the resistance on a bare controller or on my working half between C0 and R0, I get >10MOhms while I get barely half that on the problematic one. I will try to solder a new controller onto a new board, be extra careful and report back.

If by any chance someone who knows what they're doing has some insight, it would be greatly appreciated 😄

skull141209, 2023-11-17:
LoL I've just have exactly problem with my new build

kubroid, 2023-12-21:
Same issue with the left RC1-1 key :(

saseba, 2024-09-27:
I had the same issue on a Build. Culprit was most likely Flux residues underneath the Controller/Between Pins.

I cleaned the Board using Isopropyl Alcohol (99%). Underneath controller is tricky, so I tented th PCB and used Isopropyl allow the Flux to flow downward. After that I gently heated the Area of the Controller (guess 60°C) to get the Isopropyl to evaporate and stop the Flux from causing shorts again.

For next Build I recommend to use short diode legs to connect Controller and PCB so you could use less solder (equals less flux)  to to better Heattransfer between the Pads. At least that's my impression.

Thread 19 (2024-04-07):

right hand board unresponsive unless flashed with left hand side FW

boogaloodude, 2024-04-07:
I am using the reference ZMK FW.  Left side board works great.  Right hand board is unresponsive unless flashed with the left side FW.  Is this an indication that I've somehow bungled the build?  Or an actual issue with the reference ZMK FW?

Cirius1792, 2024-12-12:
Same here, any hint on a solution?

Cirius1792, 2024-12-12:
Right after the comment I arrived to the obvious solution myself.

The left part of the keyboard is the main one. The right side communicate through the left side. So having both halves powered on at the same everything works fine.

The reason why I discovered it so late is because none of my halves work on battery power... but this is another story

burgessa23, 2025-01-24:
I'm having an issue where the right side won't work on battery. What was the problem with yours?

Cirius1792, 2025-01-24:
I forgot to solder the pins of the power switches 🙃

isakbosman, 2025-03-23:
> I am using the reference ZMK FW. Left side board works great. Right hand board is unresponsive unless flashed with the left side FW. Is this an indication that I've somehow bungled the build? Or an actual issue with the reference ZMK FW?

@boogaloodude In a wireless setup with ZMK, that is standard because the left side acts as the central in the bonding process unless you use a dongle.

isakbosman, 2025-03-23:
> I'm having an issue where the right side won't work on battery. What was the problem with yours?

Use a multimeter to test the GND and VCC when on battery only. If you get the expected voltage (3.3V) then its often the power switch like @Cirius1792  reported, otherwise its often the pads on the back (specifically B+). Just try to resolder those better

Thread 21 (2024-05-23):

FEAT Request: JST Header, Bigger Battery Compartment

saseba, 2024-05-23:
Hi,

I was about to order parts for a TOTEM Build when I noticed that beekeeb seems to sells a Version of the Totem that has JST Connector for Battery above the Diodes array [1] . They also altered the outside dimension of the Case to fit a Battery in there (above the array).
Since I am a Fan of not soldering batteries  and also struggle to find a local source (for insurance reasons) for a tiny 22x15x7.5 Lipo (751517 walkera 100mah was mentioned) I wanted to make this Feature request to be considered in possible future iterations of the totem.

I guess a LP-401230 could be fitted above the Diodes Array if the Space there is just slightly increased. Currently it should have approx 7 x 11.5 x 48 mm.
From the Meshfiles I measured  with of 11.5 mm, so just 0.5  (+.25 tolerance maybe) seem to be missing.
Maybe even the outside dimensions could be maintained.

[1] https://shop.beekeeb.com/product/pre-soldered-wireless-totem/

BildermanKawasaki, 2025-07-03:
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

This project is very close to the one Beekeeb is actually selling and has the case/battery setup you described other than the JST.
https://github.com/Endracion/TOTEM-SHIFT

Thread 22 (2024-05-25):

m2 screw size for the case

krossov, 2024-05-25:
Hi,

I am in the process of acquiring part to build the TOTEM and I wonder what size m2 screw do you recommend to assemble the case, please ?

Thx.

saseba, 2024-07-18:
Build guide lists M2x6mm:
6mm M2 countersunk screws

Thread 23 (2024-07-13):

Battery sourcing?

MatthewEdge, 2024-07-13:
Less an issue and more a question as I couldn't find it in the build guide or the written post: where did you end up sourcing your batteries for the wireless version from? 👀 I've been having quite the difficulty finding a battery that fits!

Cheers for a fantastic project overall!

spamwax, 2024-07-14:
this should fit:
https://www.aliexpress.us/item/2251832763323258.html

MatthewEdge, 2024-07-14:
Thank you!

Closed 2024-07-14.

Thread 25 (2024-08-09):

Seeed Studio Fusion PCB Issues

Endracion, 2024-08-09:
After downloading the zip file and uploading it to their system, it gives the following errors:

Drill file not found. Please check that you have included the NC drill file in Excellon format. [Help](http://support.seeedstudio.com/knowledgebase/articles/1977138)

Outline not found. Please ensure you have an outline drawn in one of the files, ideally in a dedicated outline layer and that this layer is named appropriately (.GML, outline etc.) [Help](http://support.seeedstudio.com/knowledgebase/articles/1977141)

Parameters could not be extracted. Please try again or enter your board parameters manually. You can still add them to the cart but some automatic features will be restricted. [More info](http://support.seeedstudio.com/knowledgebase/articles/1977135)

--

So more importantly than the sizing, the Drill and Outline file don't seem to be compatible? Could there be an updated version?

Thanks.

that-ambuj, 2024-12-02:
Could try opening the .kicad file in Kicad Pro and exporting to gerber with the options to include drill files? Also look for related options to export the outline.

endikallanomatxin, 2024-12-27:
Same issue here.

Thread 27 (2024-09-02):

Case Step/STL files aren't recognisable by JLC3DP

Sarteg, 2024-09-02:
I tried to upload the step/stl files to JLC3DP to have the case printed but keep getting error.
Their support person tried to open the files directly using their software but failed with the following error:
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

I am not sure where the problem is was hoping if someone can take a look?

Kcebnelloh, 2024-11-27:
You don't need any software for ordering from jlc3dp. Just visit this [website](https://jlc3dp.com/3d-printing-quote) and drag and drop the files you want to print.

gienub, 2025-01-26:
This is still an issue using their upload tool on the website. Any pointers on a possible fix?

DancingSpell, 2025-07-30:
I had the same problem when downloading the step/stl files individually and trying to upload to jlcpcb (or indeed open for viewing/editing). However problem did not occur when I downloaded the entire repository as a zip file, and then dragged the step files direct from the zip into jlcpcb web interface. Hope this works for you too.

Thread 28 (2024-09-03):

JLCPCB Questions on PCB file

loosche, 2024-09-03:
Thanks so much for all this work you've done and sharing it with us all. I've ordered all the parts and am going to try and put it together, wish me luck!

However, I did get an email from JCBPCB after uploading the PCB files where they asked the following question:

_Sorry to bother you, but we'd like to confirm with you an issue found when engineer making production file of your PCB order.
As shown below, shall we remove the indicatd texts in solder mask layer? Or just proceed as per your file?_

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

I asked them to remove the text layer, but figured maybe I should let you know in case you wanted to update anything.

Thanks again!

loosche, 2024-10-03:
Putting it all together and it seems to work. So I guess the text layer didn't matter after all. Thanks again!

Closed 2024-10-03.

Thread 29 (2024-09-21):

Unable to recharge

gkaldev, 2024-09-21:
Thanks for writing the detailed build guide! I was able to make a totem without much difficulty.

However I'm unable to charge the keyboard. The keyboard turns on and seems to be fully functional otherwise. All keys work, bluetooth connectivity is great, and all zmk functionality works as expected. I see the battery level in the system power menu (the batteries I used were delivered at 70%, and they are now at 52% decharging slowly as expected, but whatever I try I'm not able to increase the charge.

I've tried the following:
- connecting the left half via USB C to my laptop with keyboard power switch off
- connecting left half via USB C to external power brick
- same as above but leaving the keyboard power switch ON

But regardless of what I try I can't get the charge level to go up (even after waiting overnight).

This is my first wireless keyboard, and first ZMK, so I wanted to make sure I wasn't just doing something stupid here.

Closed 2024-09-21.

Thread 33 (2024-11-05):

PCB vendor say gerber file is missing "keep out" layer

koha13, 2024-11-05:
I use local PCB vendor to build pcb. When i send them gerber file, they said that the design is missing keep out layer.
I dont know what it means. Any help

rroels, 2024-11-08:
Which manufacturer is this?

The files in the gerber zip should be sufficient for production. I had no issues with JLCPCB.

As far as I know, Kicad (the software used to design this PCB), doesn't even have the concept of a dedicated keepout layer. Kicad just embeds the keepout zones as part of the other layers. Dedicated keepout layers is something found in other software like Altium, but this is definitely not a requirement for getting PCBs manufactured. So it's weird that they would demand this...

You can try explaining that there is no keepout layer, and that they can add an "empty" keepout layer themselves, if they really need one.

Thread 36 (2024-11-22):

Which Seeed XIAO board version to use for wireless build?

that-ambuj, 2024-11-22:
I was looking to buy the micro-controller to build this keyboard and I see two options for Seeed XIAO BLE on the website I usually order from:

1. [Seeed Studio XIAO ESP32S3 – 2.4GHz WiFi, BLE 5.0](https://robu.in/product/seeed-studio-xiao-esp32s3-2-4ghz-wifi-ble-5-0/) - This is a cheaper version with an ESP32 chip I assume.
2. [Seeed Studio XIAO BLE nRF52840](https://robu.in/product/seeed-studio-xiao-ble-nrf52840/) - This is double the price of the previous option with a different chip.

Please help me decide because I don't want to buy the wrong part.

that-ambuj, 2024-11-22:
P.S.: There are other versions available such as the [SAMD21 version](https://robu.in/product/seeedstudio-seeeduino-xiao-pre-soldered/) available on the website. See the search results here: https://robu.in/?s=seeed+xiao&post_type=product&dgwt_wcas=1 and LMK if you think one of them is useful.

Kcebnelloh, 2024-11-27:
From what I understand you have to go with the Seeed Studio Xiao BLE nRF52840. I am not sure about this tho. I am building the wired version right now and I initially bough the wrong microcontroller (esp based) and it was impossible to flash.

that-ambuj, 2024-11-27:
@Kcebnelloh Yeah, I checked ZMK's docs for flashing the SEEED XIAO and they barely mention the ESP32 version. Also, I saw an open issue for adding support for ESP32 during my research; so I figure nrf52080 must be the one.

Thanks for the help!

Closed 2024-12-02.

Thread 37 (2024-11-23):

Can a different reset button between used?

that-ambuj, 2024-11-23:
The Alps reset mentioned in the buildguide is not available in my country. Can I use something else like this: https://amzn.in/d/hXtKUwA ?

Kcebnelloh, 2024-11-27:
The footprint of the part needs to match so that you can solder it into the pcb correctly. Also if you want to use the case, then it has to be exactly the same part. I found them here on aliexpress: https://de.aliexpress.com/item/1005005594042307.html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

that-ambuj, 2024-11-27:
Unfortunately, Aliexpress is not available in my country otherwise this would've been a whole lot easier.

Closed 2024-12-02.

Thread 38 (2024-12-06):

Accurate Battery Level Indicator

dconz13, 2024-12-06:
Hey there GEIGEIGEIST! Thanks for making the Totem! It's an awesome board. I'm looking for guidance on getting more accurate battery information through ZMK. I've tried charging both halves of the board via the USB on my PC as well as 5V usb adapters and haven't seen the battery go up higher than ~50% on the right half and ~80% on the left. Do you know the answers to the follow:

Does the power switch need to be turned on for the battery to charge?
Is there a ZMK configuration that can be added for the seeedxiao to get more accurate battery information?

 I'm using the below script to check the battery on Linux:

```
from dbus_next.aio import MessageBus
from dbus_next.constants import BusType
import asyncio
BLUEZ = "org.bluez"
#replace hci0 with your bluetooth adapter name and FF_FF_FF_FF_FF_FF with your keyboard address
BLUEZ_PATH = "/org/bluez/hci0/dev_FF_FF_FF_FF_FF_FF"
GATT_SERVICE = 'org.bluez.GattService1'
GATT_CHARACTERISCITC = 'org.bluez.GattCharacteristic1'
GATT_CHARACTERISCITC_DESCR = 'org.bluez.GattDescriptor1'
BATTERY_UUID = "0000180f-0000-1000-8000-00805f9b34fb"
BATTERY_LEVEL_UUID = "00002a19-0000-1000-8000-00805f9b34fb"
BATTERY_USER_DESC = "00002901-0000-1000-8000-00805f9b34fb"

loop = asyncio.get_event_loop()

async def main():
    bus = await MessageBus(bus_type=BusType.SYSTEM).connect()
    # the introspection xml would normally be included in your project, but
    # this is convenient for development
    introspection = await bus.introspect(BLUEZ, BLUEZ_PATH)

    device = bus.get_proxy_object(BLUEZ, BLUEZ_PATH, introspection)

    for svc in device.child_paths:
        intp = await bus.introspect(BLUEZ, svc)
        proxy = bus.get_proxy_object(BLUEZ, svc, intp)
        intf = proxy.get_interface(GATT_SERVICE)
        if BATTERY_UUID == await intf.get_uuid():
            for char in proxy.child_paths:
                intp = await bus.introspect(BLUEZ, char)
                proxy = bus.get_proxy_object(BLUEZ, char, intp)
                intf = proxy.get_interface(GATT_CHARACTERISCITC)
                level = int.from_bytes(await intf.call_read_value({}))
                if BATTERY_LEVEL_UUID == await intf.get_uuid():
                    props = proxy.get_interface('org.freedesktop.DBus.Properties')
                    for desc in proxy.child_paths:
                        intp = await bus.introspect(BLUEZ, desc)
                        proxy = bus.get_proxy_object(BLUEZ, desc, intp)
                        intf = proxy.get_interface(GATT_CHARACTERISCITC_DESCR)
                        name = "Main"
                        if BATTERY_USER_DESC == await intf.get_uuid():
                            name = bytearray(await intf.call_read_value({})).decode()
                    print(name + ": ", str(level))

loop.run_until_complete(main())
```

kentonis, 2025-05-01:
This might be a little old, but just in case someone else runs across this: The totem does need to be turned on to charge. The power switch is in series with the xiao on the positive lead of the battery (the xiao does not provide a method for connecting the charging circuit separately).

I've checked this with a multimeter on the totem I just built as well as traced the PCB routes in the kicad file.

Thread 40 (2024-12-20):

Qmk firmware flashing

Moholic, 2024-12-20:
Tried to flash the firmware through vial-qmk but wasnt able to make it work. Seemed to flash the layout of the left half to both sides.

Any help appreciated.

Moholic, 2024-12-23:
Ok, so I tried around a bit...
loading the precompiled firmware was sucessful - giving me only 4 of the 5 keyboard layers (adjust is missing)
Compiling via qmk works for the default, not for the vial enabled version.
Flashing the compiled version would flash me the left side on both halfs (mirrored on right).
Was trying to flash with the following command:
- qmk flash -kb geigeigeist/totem -km default
- qmk flash -kb geigeigeist/totem -km default -bl uf2-split-left
and
- qmk flash -kb geigeigeist/totem -km default -bl uf2-split-right
respectively.

Anyone able to help on the correct command? or am I just stuck with the precompiled firmware?

JMulder99, 2024-12-31:
Hi,
I've been trying to flash using WSL (Ubuntu). It compiles successfully for the default (vial enabled) and my custom keymap.

However, when I try to flash the keyboard, it is stuck at "Waiting for the drive to deploy". Does anyone know is missing?

Moholic, 2024-12-31:
Hi,
Just press the reset-button twice and the device mounts as an external drive.

JMulder99, 2025-01-03:
I got it to work without the flash command, because WSL fails to recognize the drive.

- I added `split_keyboard = yes` in `rules.mk`.
- I removed `reverse_hands = true` in `keyboard.json`. It causes the master to flip to RIGHT even though I set it to LEFT. I have no idea why that was put in.
- Then I presses the reset twice, and drag&dropped the same `.uf2` file on both halves.

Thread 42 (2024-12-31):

[Question] Does it work with Kailh Choc V2 Switches and Sockets?

WreckingBANG, 2024-12-31:
Does it work with Kailh Choc V2 Switches and Sockets?

moshewe, 2025-02-12:
Choc v2 switches have an extra stabilizer pin, so you need a compatible PCB with room for said pin. The current Totem pcb doesn't support this AFAIK

WreckingBANG, 2025-02-12:
Ok, thank you.

Closed 2025-02-12.

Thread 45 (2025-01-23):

ZMK Flash, drag and drop causes drive to disconnect and reset files.

Chris-LewisI, 2025-01-23:
Every time I try to glad my Xiao with the ZMK UF2 for my Bluetooth set up the drive disconnects.

When I reopen the drive it has the original files all over again even if I deleted them previously.

isakbosman, 2025-03-23:
I'm not sure if this is still helpful or if it can help someone else. This is standard behavior as the MCU restarts once the firmware file uploads. The best thing to do is to either hit the reset button afterwards, or unplug and plug the left side in again. Try to type to see if the keys work. Do the same for the right side (it doesn't work without the left side *depending on your setup*)

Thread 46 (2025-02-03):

[BLE] Not being able to type when connecting via USB

TannerGabriel, 2025-02-03:
## What is happening

When I connect my BLE totem via USB to charge the battery, I can no longer type via Bluetooth.

## Expected behavior

When connecting via USB, the keyboard still works as expected.

## Possible cause

The default output priority of the USB seems to be higher than that of the Bluetooth connection ([ZMK documentation](https://zmk.dev/docs/troubleshooting/connection-issues#using-bluetooth-output-with-usb-power)). This should probably be changed for the precompiled firmware.

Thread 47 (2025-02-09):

[BLE] Bluetooth can't connect with firmware with custom keymap

mgkz-git, 2025-02-09:
Hello,

As stated in the title when using a modified ZMK firmware (only changing the keymap) the keyboard can't be connected with bluetooth.
It is still showing when searching new device but when I try to connect to it nothing happens.

But with the precompiled firmware the keyboard can connect with bluetooth.

Can I have some help with this ?

Thanks in advance :)

mgkz-git, 2025-02-09:
I've found the problem.

I didn't have a key with the "bluetooth clear all profiles" 😅

Closed 2025-02-09.

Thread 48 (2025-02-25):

STL files won't load in prusaslicer

ericsoderstrom, 2025-02-25:
I'm running the latest stable release of PrusaSlicer (2.9.0) . when attempting to load the case STLs I get the following error:
```
[2025-02-25 12:48:46.810780] [0x0000000109d20580] [error]   Something is syntactically very wrong with this ASCII STL!
```

I'm also unable to load the STLs with a web viewer like https://grid.space/kiri/

loading step files doesn't work either, and gives:
```
**** ERR StepFile : Undefined Parsing: Line 8: Incorrect syntax: unexpected QUID, expecting STEP    ****
TOTEM_case_ble_bottom_L_V.08.step: basic_string
```

are the case files corrupted somehow?

ericsoderstrom, 2025-02-25:
I'm an idiot. I'll leave this issue undeleted in case there are any other idiots out there like me:
I was just using `curl -O` / rick-click save-as on the raw file links from the github web view. I guess that just downloads the html page representing the raw file. lol. Anyway, cloning the git repo and using the files from the local clone works fine

Closed 2025-02-25.

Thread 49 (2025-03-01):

Bluetooth is immediately disconnected when connecting totem.

tdarshana, 2025-03-01:
Facing issue when connecting totem to MacBook (MacOs 15). I can see its discovered in Bluetooth settings, and then can see connect button, but when I clicked it, it shows the spinner for a moment (like 1s) and then again shows connect button. Somehow connection establishment was not successful. I can see following logs in my system log.

I tried restarting mac, and reconnect, disabling and enabling bluetooth, and with a separate iPad, and fully charged both keyboard parts before testing, but none was successful.

Greatly appreciate any help here. I'm trying with the provided firmware in this repo for BT.

```
default	12:50:05.091779+0800	bluetoothd	macLeDeviceConnectionParametersUpdated: LE HID "TOTEM" cache device's preference CI is 30.00 ms
default	12:50:05.091815+0800	bluetoothd	isLowLatencyBLEHID: Device "TOTEM" is appearanceValue(0x3c1)
default	12:50:05.091867+0800	bluetoothd	isLowLatencyBLEHID: Device "TOTEM" is VID(0x1d50) / PID(0x615e)
default	12:50:05.091886+0800	bluetoothd	isLowLatencyBLEHID: Device "TOTEM" is appearanceValue(0x3c1)
default	12:50:05.091936+0800	bluetoothd	isLowLatencyBLEHID: Device "TOTEM" is VID(0x1d50) / PID(0x615e)
default	12:50:05.092576+0800	bluetoothd	macLeDeviceConnectionParametersUpdated: LE HID "TOTEM" current 30.00 ms latency(0) appearanceValue(0x3c1) updated
default	12:50:05.095699+0800	bluetoothd	Device ready - {cbuuid: 7BE648C9-1799-8AD1-A369-771858B73122, devicename: TOTEM, lmHandle: 0x44, adv-addr: EF:27:D4:02:91:94-Random, resolved-addr: , result: 0}
default	12:50:05.111638+0800	bluetoothd	Device found: CBDevice 7BE648C9-1799-8AD1-A369-771858B73122, BDA EF:27:D4:02:91:94, Nm 'TOTEM', PID 0x615E (?), VID 0x1D50, VS 1, DsFl 0x200000 < Connections >, DvF 0x40000210000 < HIDGoodBehavior Central Connectable >, CnS 0x400000 < BLE >, Aprc Keyboard, BTv 5.4, CF 0x80804200000 < Connections New DiscoveryFlags Attributes >
default	12:50:05.625581+0800	bluetoothd	DIS for device 7BE648C9-1799-8AD1-A369-771858B73122 DIS Model number: TOTEM
default	12:50:05.704642+0800	bluetoothd	isLowLatencyBLEHID: Device "TOTEM" is appearanceValue(0x3c1)
default	12:50:05.704885+0800	bluetoothd	isLowLatencyBLEHID: Device "TOTEM" is VID(0x1d50) / PID(0x615e)
default	12:50:05.705310+0800	bluetoothd	isLowLatencyBLEHID: Device "TOTEM" is appearanceValue(0x3c1)
default	12:50:05.706147+0800	bluetoothd	isLowLatencyBLEHID: Device "TOTEM" is VID(0x1d50) / PID(0x615e)
default	12:50:05.706391+0800	bluetoothd	switchLEHIDsConnectionInterval_block_invoke: Device "TOTEM" is Compatible LE HID
default	12:50:05.706927+0800	bluetoothd	switchLEHIDsConnectionInterval_block_invoke: LE HID "TOTEM" switching to 15.00 ms latency(0) appearanceValue(0x3c1) CELength(4)
default	12:50:05.783302+0800	BTLEServer	Updated DeviceInformation for TOTEM‘s ModelNumber - TOTEM
default	12:50:05.837832+0800	BTLEServer	Updated DeviceInformation for TOTEM‘s ManufacturerName - ZMK Project
default	12:50:05.847970+0800	BluetoothUIServer	LEHIDConnectionComplete - VID:0x1D50 PID:0x615E “TOTEM”: no custom info found
default	12:50:05.896083+0800	BTLEServer	Updated DeviceInformation for TOTEM‘s PnP - PID:0x615E VID:0x1D50
default	12:50:06.022196+0800	bluetoothd	macLeDeviceConnectionParametersUpdated: LE HID "TOTEM" cache device's preference CI is 15.00 ms
default	12:50:06.022224+0800	bluetoothd	isLowLatencyBLEHID: Device "TOTEM" is appearanceValue(0x3c1)
default	12:50:06.022268+0800	bluetoothd	isLowLatencyBLEHID: Device "TOTEM" is VID(0x1d50) / PID(0x615e)
default	12:50:06.022289+0800	bluetoothd	isLowLatencyBLEHID: Device "TOTEM" is appearanceValue(0x3c1)
default	12:50:06.022614+0800	bluetoothd	isLowLatencyBLEHID: Device "TOTEM" is VID(0x1d50) / PID(0x615e)
default	12:50:06.022634+0800	bluetoothd	macLeDeviceConnectionParametersUpdated: LE HID "TOTEM" current 15.00 ms latency(0) appearanceValue(0x3c1) updated
default	12:50:06.063726+0800	bluetoothd	Device disconnected - {cbuuid: 7BE648C9-1799-8AD1-A369-771858B73122, devicename: TOTEM, lmHandle: 0x44, adv-addr: EF:27:D4:02:91:94-Random, resolved-addr: , result: 0}
default	12:50:06.080256+0800	bluetoothd	Device lost: CBDevice 7BE648C9-1799-8AD1-A369-771858B73122, BDA EF:27:D4:02:91:94, Nm 'TOTEM', PID 0x615E (?), VID 0x1D50, VS 1, DvF 0x40000210000 < HIDGoodBehavior Central Connectable >, CnS 0x400000 < BLE >, Aprc Keyboard, BTv 5.4, CF 0x800200000 < Connections DiscoveryFlags >

```

https://github.com/user-attachments/assets/4ad4daf7-ed48-4daa-86e2-507558a7e0ad

tdarshana, 2025-03-01:
Was able to connect to my Mac after a settings reset. followed here - https://zmk.dev/docs/troubleshooting/connection-issues#reset-split-keyboard-procedure

Closed 2025-03-01.

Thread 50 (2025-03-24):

BLE Totem reset switch won't work

Biensta, 2025-03-24:
I doublechecked my solder and I checked the images and the buildguides but the reset switch wont work I tried everything

jakubjun, 2025-04-04:
had the same issue after soldering. check if you've put enough solder into the joints here

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

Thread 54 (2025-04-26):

Bluetooth connections

frtytw, 2025-04-26:
I'm having trouble re-establishing connections with computers.
The board will either show up, and does not want to connect, or will not connect at all.
I have stuck to the default keymap, for testing, etc.

I have tried:

1. Reseting (hold TAB, hit ESC and let go, hit Q)
2. BLT_CLR (hold TAB, hit ESC and let go, hit W)
3. BLT_NEXT (hold TAB, hit ESC and let go, hit R)
4. Re-flashing with the provided firmware
5. Building firmware from zmk-config-totem

Does anyone have ideas?

janpfischer, 2025-05-05:
@frtytw For me I fixed it.
The build.yml in the cmk-config-totem says you do not need a setting reset firmware (https://github.com/GEIGEIGEIST/zmk-config-totem/blob/master/build.yaml#L6) for seeeds but I just tried it.

I created a settings reset firmware like documented here: https://zmk.dev/docs/troubleshooting/connection-issues#building-a-reset-firmware
I forked the https://github.com/GEIGEIGEIST/zmk-config-totem repo and added the firmware to my build.yml.
After that I set the seeed into bootloader mode and flashed the firmware.
Right after that I set the seeed into bootloader mode again and flashed the normal firmware (from my build) for the left side.
I was able to connect via Bluetooth first try again.

Hope this helps!

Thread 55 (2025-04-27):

M2 standoff cannot be inserted into the hole

chengyuancong, 2025-04-27:
Diameter of holes in the top case is about 3.2mm but diameter of M2 standoff is about 3.5mm. I tried m2 standoff from different sellers but none of them can be inserted. Did I do sth wrong?

frtytw, 2025-04-27:
Mine seated snugly with a bit of pressure.
They need to be snug, in order not to fall out when assembling.

metzger100, 2025-06-05:
Is it too obvious, or is a drill not the right tool for this problem? I noticed the issue as well and still ordered 4 mm standoffs because I thought I could widen the holes with a drill (parts didn't arrive yet so I don't know if drilling works). With a resin print that shouldn’t be an issue, and even with a filament print you should be able to enlarge the holes with a drill.

sinefabula, 2025-06-05:
@metzger100 yes, a drill should definitely do the job. I just think it should not be a part of the regular build process when the case is 3D printed and can be easily modified to take whatever parts are readily available, not vice versa. Thanks for the drilling tips though, didn't know that, and that is helpful!

metzger100, 2025-06-05:
@sinefabula

> to take whatever parts are readily available

Exactly. If the holes for the standoffs are to small you can change them with a drill. If they are to big, you are in trouble (fill it with hot glue and redrill? Not everyone has hot glue). I guess everyone has a drill at home. The too small holes are better in my opinion.

metzger100, 2025-06-13:
Okay. Feedback time.

I used a 3.5mm and a 4mm drill to widen the holes. It worked, but there are a few problems with this method.

1. You will probably destroy the countersinks for the screws on the top. But this is not a big deal. You use the screws on the top to cover the holes. So visually it doesn't make much of a difference (in one hole the screw is not centered because the widening has shifted the hole, so a small gap is visible). I had to use a small hammer to get the 4mm diameter standoffs into the widened holes so they are strong enough to hold without the screw on top. If you want to be sure, you can use super glue on the standoffs to glue them into the holes.
2. Also in my case the walls of the socket for the standoffs became quite thin. I used the JLC Black Resin which has good values for this kind of stress: Elongation at break, impact strength, tensile strength (higher is better). I am not sure if the Imagine Black resin could withstand this drilling. So be carefull

Lessons Learned:
1. It would be better to have the sockets for the standoffs on the bottom parts of the case so you don't have to drill into the top parts, which is the visible part of the keyboard.
2. It would be better if the standoff sockets were thicker so you could widen the holes without risking breaking the walls of the socket. Especially if you use worse resins.

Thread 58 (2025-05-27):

Failure to detect on boot

jaeryongim, 2025-05-27:
If you turn the PC off and on with the wire connected, it will not recognize the connection and you will have to unplug and reconnect the wire.
I am using QMK, and the OS is MAC (SILICON M2) SEQUOIA.

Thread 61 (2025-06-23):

What exactly is outdated with the source firmware?

iamavolk, 2025-06-23:
First of all, great project, many thanks!

Back to the topic, though: just wanted to see what aspects of the source repo/guide are outdated (per the readme on here), as I couldn't really find anything specific upon perusing the repo itself?

Ratione, 2025-07-06:
So, Is everyone who is attempting to build the wired version just waiting until someone figures out how to make this work with the new QMK version, or do we need to look for alternative solutions, or what?

Momro, 2025-07-30:
Hi all,

I received a current qmk firmware from a friend who has a working config. I was able to compile it with current Ubuntu 24.04 in wsl with qmk vial.

Now I'm trying to publish the config and everything to github.

I forked the repo https://github.com/Momro/Totem

I also uploaded my newbie explanation how to compile the qmk-vial firmware in this readme

https://github.com/Momro/Totem/tree/main/firmware/QMK/VIAL_source/totem

I hope to upload my current firmware there as well. Hopefully tonight. I have to perform a few tests first.

iamavolk, 2025-08-15:
This is the ZMK config. The original structure was a bit off, so I updated it. Works fine.

Clone the repo and just write your own config in
totem.keymap, commit, push, and flash the produced firmware.

https://github.com/iamavolk/totem-shield-module

iamavolk, 2025-08-15:
This is the ZMK config. The original structure was a bit off, so I updated it. Works fine.

Clone the repo and just write your own config in
totem.keymap, commit, push, and flash the produced firmware.

https://github.com/iamavolk/totem-shield-module

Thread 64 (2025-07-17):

I Have burned 3 xiao boards and dont know what to do

Khyretos, 2025-07-17:
Hey there,

So i was trying to build the totem and tried to follow the instructions to the letter, until i connected the board and smoke started to come out.
After watching carefully i tried it a second time and the same happend.
and also for the third time, this time rechecking everything and checking continuity and all and it still went up in smoke. it is so bad it disables all my usb devices (because of an obvious short circuit).

I sincerely dont know what to do,

I was able to flash the firmware with no problems, but the moment i connect the thing it just goes up in smoke and i dont know whats going on.

is there anything i can check or verify? i have lost hope in this project to be honest and i just want to know if anyone has had the same experience and can point out to me if they had some luck trying something different.

the only thing i find strange is that the pin next to GND (not vcc) has continuity with ground, other than that. all pins have the correct continuity , the switches are soldered on the correct way (yes i had to redo it because i messed up my first attempt) the diodes are supposedly connected correctly (the line is on the side of the tip of the triangle with the line) the reset button has continuity with the bottom of the board and the battery sockets also have continuity with the bottom of the board.

is there anything else i can check?

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

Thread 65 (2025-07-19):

Beginner question: 1 key does not work on my right side. What can I do? :-(

Momro, 2025-07-19:
Hi all,

I was so happy that the right hand side worked. I'm a real beginner of soldering, and I was extremely happy it connected and everything. Sadly, *the last* key I tested does not work. Even when I short-circuit the pads on the back, there is no signal.

I am a real noob with a multi meter etc,, no idea how to debug this, or read https://raw.githubusercontent.com/GEIGEIGEIST/TOTEM/410e566dd47466c0b69279f0d4b3646998c663d4/docs/images/TOTEM_traces.svg

Any ideas what I could test or do? Maybe the relevant diode is off, or maybe something with the controller? :-(

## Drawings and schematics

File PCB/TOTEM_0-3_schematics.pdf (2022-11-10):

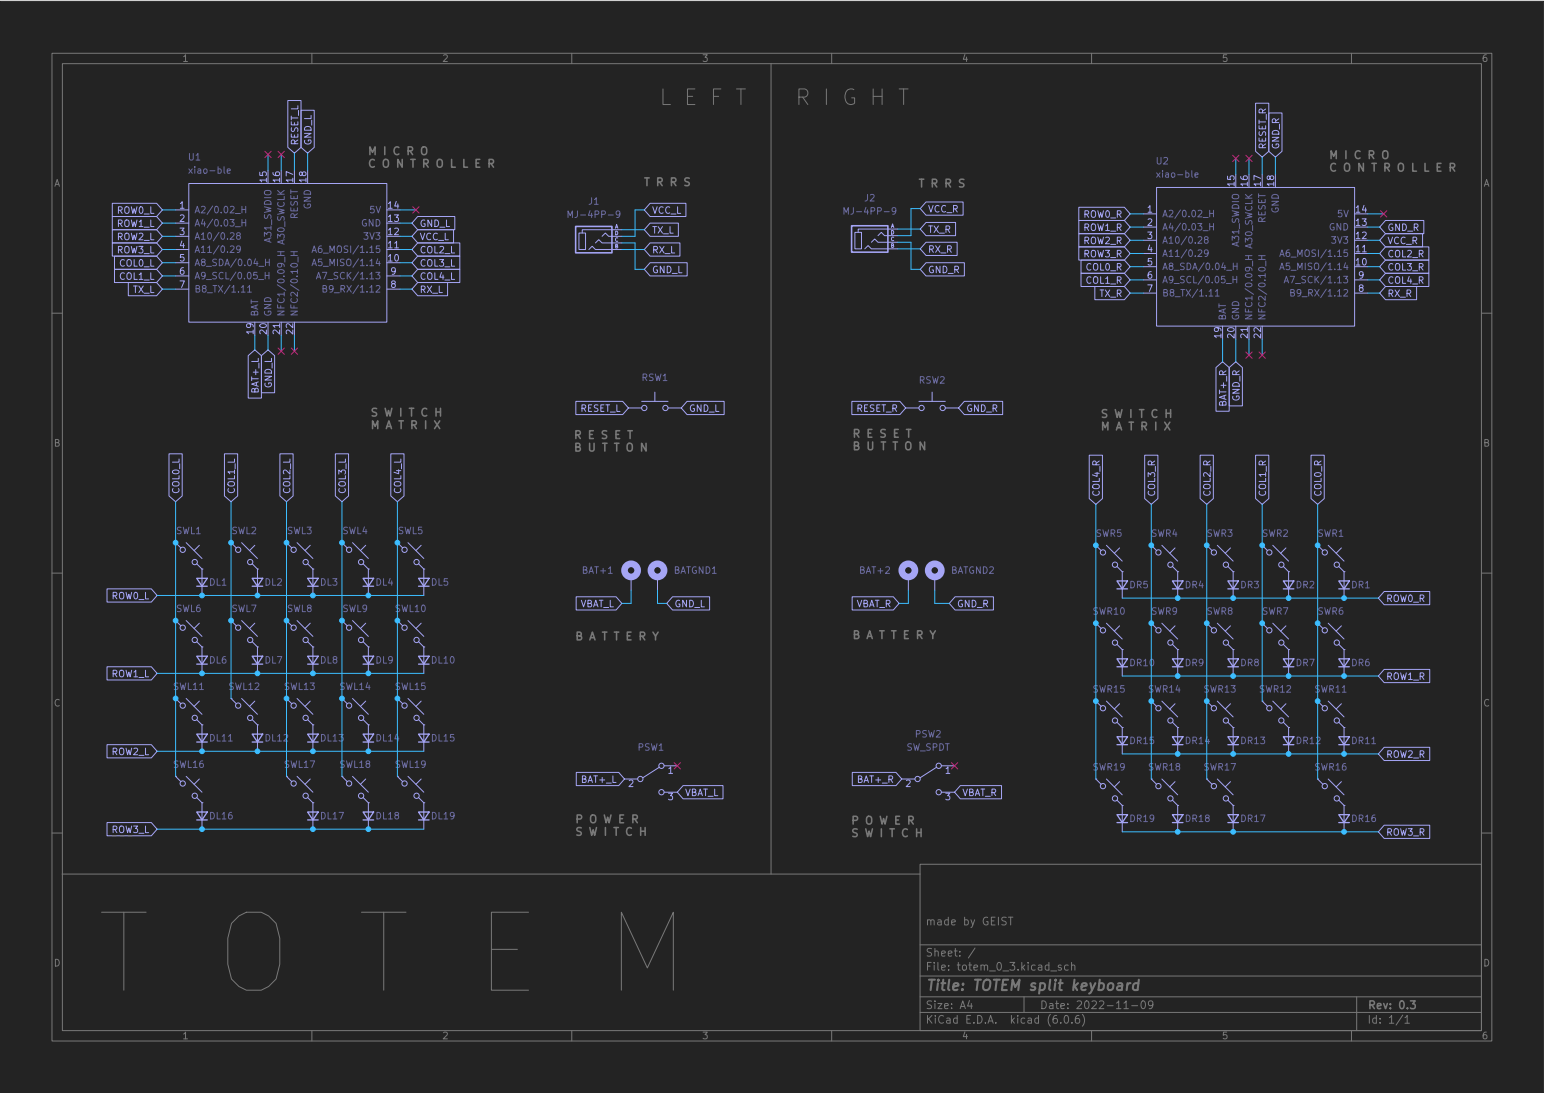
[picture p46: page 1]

Id: 1/1 Title: TOTEM split keyboard

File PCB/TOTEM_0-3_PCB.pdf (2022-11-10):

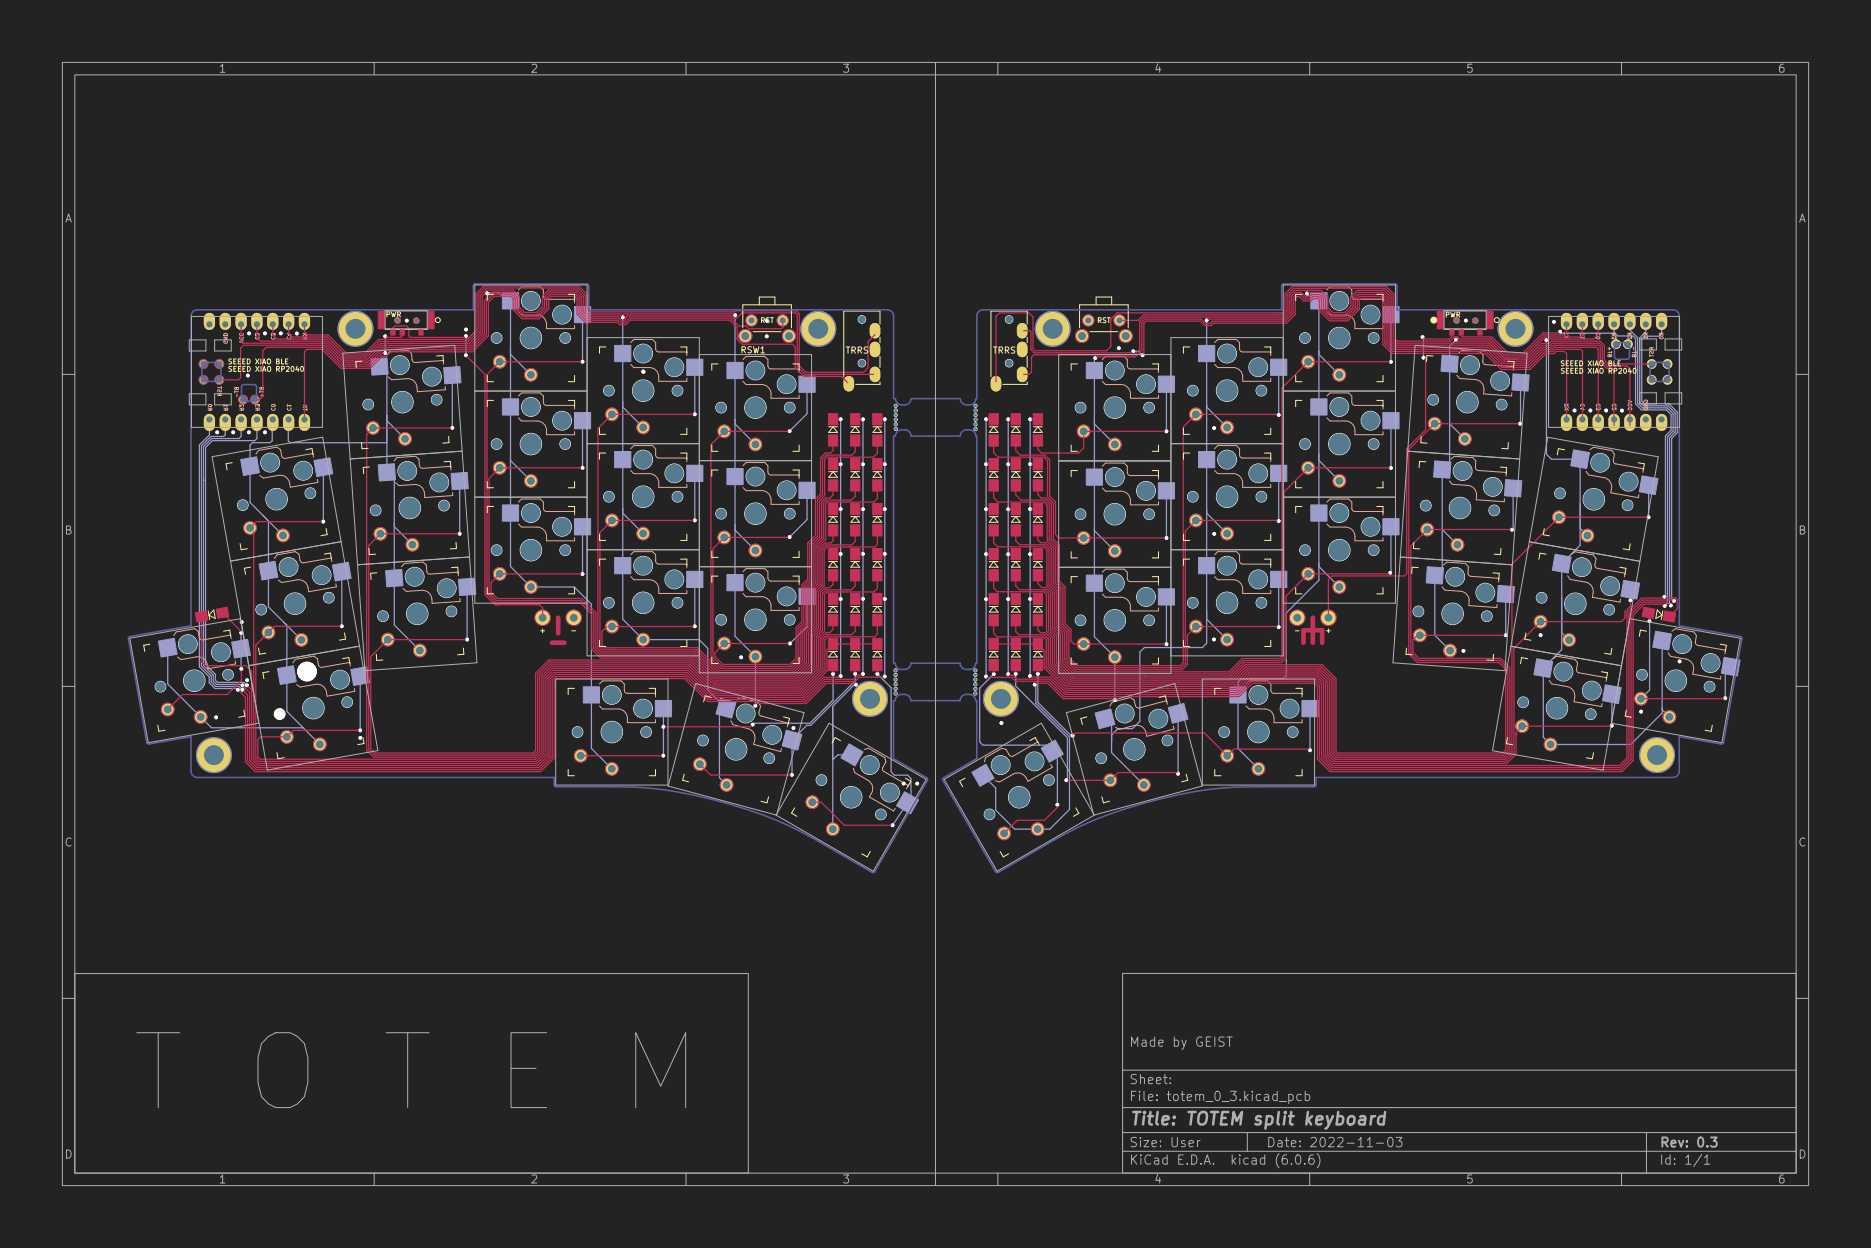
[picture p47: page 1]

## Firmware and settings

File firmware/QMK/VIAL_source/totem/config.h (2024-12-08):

// Copyright 2022 GEIST @geigeigeist
// SPDX-License-Identifier: GPL-2.0-or-later
#pragma once

#define MATRIX_ROWS 8
#define MATRIX_COLS 5

#define SERIAL_USART_FULL_DUPLEX  // Enable full duplex operation mode.
#define SERIAL_USART_TX_PIN GP0   // USART TX pin
#define SERIAL_USART_RX_PIN GP1   // USART RX pin
#define SERIAL_USART_PIN_SWAP     // Swap TX and RX pins if keyboard is master halve.
#define EE_HANDS // Split handedness via eeprom

#define RP2040_BOOTLOADER_DOUBLE_TAP_RESET
#define RP2040_BOOTLOADER_DOUBLE_TAP_RESET_TIMEOUT 500U

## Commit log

2022-11-03 case render
2022-11-04 case images
2022-11-04 case documentation
2022-11-04 add case files
    [TOTEM_case_v06_v6_Lbottom.step, TOTEM_case_v06_v6_Ltop.step, TOTEM_case_v06_v6_Rbottom.step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]
2022-11-06 update traces
2022-11-10 schematic and PCB as PDF
2022-11-10 Add KiCad files and gerbers
    [D_SOD-123.step, Kailh_socket_PG1350_optional.STEP, Kailh_switch_PG1350_optional.step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]
2022-11-13 add case options
    [TOTEM case_noPower_v06_bottomLeft.step, TOTEM case_noPower_v06_bottomLeft.stl, TOTEM case_noPower_v06_bottomRight.step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]
2022-12-12 Fixed small typographical error
    without TRRS cutout == wireless version, not wired.
2022-12-20 update case files
    [TOTEM case_noPower_v06_bottomLeft.step, TOTEM case_noPower_v06_bottomLeft.stl, TOTEM case_noPower_v06_bottomRight.step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]
2024-05-21 added tenting case options
    [TOTEMcase_v08_6mm_BLE_Tenting_Bottom_L.step, TOTEMcase_v08_6mm_BLE_Tenting_Bottom_L.stl, TOTEMcase_v08_6mm_BLE_Tenting_Bottom_R.step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]
2024-05-22 added more info and pictures to the case readme
2024-06-01 added usb tenting bottom plate
    [TOTEMcase_v08_6mm_USB_Tenting_Bottom_L.step, TOTEMcase_v08_6mm_USB_Tenting_Bottom_L.stl, TOTEMcase_v08_6mm_USB_Tenting_Bottom_R.step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]
2024-06-01 removed top piece from stl bottom plates
    [TOTEMcase_v08_6mm_USB_Tenting_Bottom_L.step, TOTEMcase_v08_6mm_USB_Tenting_Bottom_L.stl, TOTEMcase_v08_6mm_USB_Tenting_Bottom_L.stl.stl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]
2024-06-01 renamed usb bottom plate stl file
    [TOTEMcase_v08_6mm_USB_Tenting_Bottom_L.stl, TOTEMcase_v08_6mm_USB_Tenting_Bottom_R.stl]
2024-09-25 Update TOTEM_traces.svg: Add Missing Diode numbers
2024-12-08 fix standoff hole near the RST button (9mm)
    [TOTEM_case_ble_bottom_L_V.08.STL, TOTEM_case_ble_bottom_L_V.08.step, TOTEM_case_ble_bottom_R_V.08.STL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]
